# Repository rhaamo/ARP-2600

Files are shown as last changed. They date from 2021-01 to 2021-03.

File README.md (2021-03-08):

# ARP 2600
 
# Sources
- Patroche who did a lot of reverse on the schematics and PCBs http://www.crazy-patroche.com/article-clonage-du-arp-2600-120886590.html
- The 'full service manual'
- https://www.synthpatchers.com/wp-content/uploads/2013/05/ARP-2600-Slider-Locations-and-Values.pdf

# Status

| board | schematics | reviewed | pcb | tested |
| --- | --- | --- | --- | --- |
| 4014 ring modulator | done | | | |
| 4015 sample & hold  | done | | | |
| 4019 VCA | done | | | |
| 4020 ADSR | done | | | |
| 4022 Noise | done | | | |
| 4027 VCO | done | | | |
| 4072 VCF | done | | | |
| Board 1 | done | | | |
| Board 2 | done | | | |
| Board 2-1 | done | | | |
| Board 3 | done | | | |
| Board 4 | done | | | |
| Board 4-1 | done | | | |
| Board 5 | done | | | |
| Board 5-1 | done | | | |

# Notes
## All panel jacks
- check if they are properly labelled/wired

## Original schematics
- The jacks have S and T, S represent SHUNT, T for TIP, and the circle seems the SLEEVE
- an UP arrow is +15V, a DOWN arrow is -15V

## Patroche reverse
- Some typos presents, missing items in BOM, and some components are mislabelled in the PCB placement pictures

## Board 1
- On patroche, R27 (near S7) is R36

## Board 3
Adaptations have been made for 4072 VCF instead of 4012.

## Board 4
- Shouldn't `E57` and `E65` reverb input and output be internal RCA ?
- Some jacks / solder points don't have a number on schematics (given one arbitrary)
- two pairs of components have the same number too (changed one)

## Board 4-1
- one duplicate reference, some missing in patroche bom, one value differs from schematics

## Board 5-1
- In patroche PCB view, pin 1 and 4 are swapped from the schematics
- see notes in schematics for renamed parts

# Guidelines
- keep the same number as original schematics (R123, CR42, etc.)
- uses different prefix for Resistors (R), Trimmers (VR) and Faders (?), also to do that on existing made schematics.
- Jack sockets are `Exx`, hole for soldering a PANEL one or other wiring is `Txx`
- Use the PCBs from patroche to check for jacks on PCB vs panel and the associated 'pads' for the flying wires between boards
- Properly document thoses 'flying wires' like https://raw.githubusercontent.com/CreativeInquiry/ARP-2600/master/ARP-2600-Harness-Wiring.jpg but SVG/PDF with the board delimited and points/wire visibles. we don't have to wait until PCBs are done for that.
- PSU won't (yet) be recreated, you can use a newer, better one like https://www.muffwiggler.com/forum/viewtopic.php?t=130814&highlight= (PCB is available in 115 and 230V)
- Keyboard is not planned as CV/Gate is available on the panel, use your own midi-to-cv or keyboard with CV/Gate output
- Properly document in a separate file all changes between schematics/patroche (and our renaming of duplicates)

# Plans
1. Make identical boards as original/patroche
2. Maybe re-add the panel jacks to the bottom of PCBs
3. We will see

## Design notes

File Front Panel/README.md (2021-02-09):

- ARP 2600 Panel.orig.dxf

The original DXF converted from Patroche PDF

- ARP 2600 Panel.edited.dxf
- ARP 2600 Panel.edited.dwg

The DWG and DXF files edited to accomodate the changes in the BOM:

- power switch removed (it's integrated in the power socket)
- two leds (size changed, +1 led)
- jack headphones size update
- switches shape change
- gain pot size changed

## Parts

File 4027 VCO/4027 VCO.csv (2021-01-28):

Reference | Quantity | Value | Footprint | Datasheet | Notes
A1 | 1 | CA3086
C1 | 1 | 680pF |  | ~ | mica
C2 | 1 | 5pF |  | ~
C3 C6 | 2 | 10nF |  | ~
C4 C5 | 2 | 1uF 35V |  | ~ | chemical or tantal
J18 | 1 | L.F. CAP |  | ~
J19 | 1 | TRIM INPUT |  | ~
J2 | 1 | CONT. INPUT |  | ~
J5 | 1 | SAW. OUT |  | ~
J6 | 1 | POSITIVE SUPPLY |  | ~
J7 | 1 | GROUND |  | ~
J8 | 1 | NEGATIVE SUPPLY |  | ~
Q1 | 1 | 2N3906 | Package_TO_SOT_THT:TO-92_Inline | https://www.onsemi.com/pub/Collateral/2N3906-D.PDF
Q2 | 1 | 2N3904 | Package_TO_SOT_THT:TO-92_Inline | https://www.onsemi.com/pub/Collateral/2N3903-D.PDF
Q3 Q4 | 2 | 2N5459 |  | ~
Q5 | 1 | 2N4125 |  | ~
R1 | 1 | 475k 1% |  | ~
R10 | 1 | 30.1k 1% |  | ~
R11 | 1 | 3.9k |  | ~
R12 | 1 | 220R |  | ~
R13 | 1 | 1.65k 1% |  | ~
R3 R14 R21 | 3 | 1k 1% |  | ~
R15 | 1 | 8.87k 1% |  | ~
R16 | 1 | 1.37k 1% |  | ~
R18 | 1 | 47k |  | ~ | 41k ?
R19 | 1 | 68k |  | ~
R2 | 1 | 121k 1% |  | ~
R20 | 1 | 33.2k 1% |  | ~
R22 | 1 | 45.3k 1% |  | ~
R23 | 1 | 15k |  | ~
R24 | 1 | 3.3M |  | ~
R4 | 1 | 1.87k - tempco - 3500ppm 1w 3% |  | ~ | 1.87k - tempco - 3500ppm 1w 3%
R5 | 1 | 100k 1% |  | ~
R6 R7 | 2 | 61.9k 1% |  | ~
R8 R17 | 2 | 12k |  | ~
R9 | 1 | 1.5k |  | ~

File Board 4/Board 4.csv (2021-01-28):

Reference | Quantity | Value | Footprint | Datasheet
A20 | 1 | LM301 |  | http://www.ti.com/lit/ds/symlink/lm101a-n.pdf
BADSR-1 BADSR-2 BADSR-4 BVCA-5 BADSR-6 BVCA-6 BADSR-7 BVCA-7 BADSR-8 BVCA-8 SW8 BADSR-9 BVCA-9 BADSR-10 BVCA-10 BADSR-11 BVCA-11 BVCA-14 BVCA-18 BVCA-19 B42-1 B42-2 B42-3 B42-4 B42-5 B42-6 B42-7 B42-11 B42-12 B42-13 B42-14 B42-15 B42-16 B42-17 | 34 | ~ |  | ~
BADSR-5 B42-10 | 2 | +15V |  | ~
BADSR-3 B42-8 | 2 | -15V |  | ~
B42-9 | 1 | GND |  | ~
BVCA-1 | 1 | +control |  | ~
BVCA-2 | 1 | -control |  | ~
BVCA-3 | 1 | lin |  | ~
BVCA-4 | 1 | exp |  | ~
C62 C63 C64 C65 C69 | 5 | 1uF 35V |  | ~
C66 | 1 | 30pF |  | ~
C67 | 1 | 50pF |  | ~
C68 | 1 | 10uF 35V |  | ~
D21 D22 D23 D24 D25 | 5 | 1N4148 | Diode_THT:D_DO-35_SOD27_P7.62mm_Horizontal | https://assets.nexperia.com/documents/data-sheet/1N4148_1N4448.pdf
E45 E46 E47 E48 E50 E51 E52 E53 E55 E56 E57 E58 E59 E60 E62 E63 E64 E65 E66 E99 E100 | 21 | PJ301BM |  | https://www.thonk.co.uk/shop/3-5mm-jacks/
J100 | 1 | VCA OUT |  | ~
Q5 | 1 | 2N5460 |  | ~
Q6 | 1 | 2N5172 |  | ~
R170 | 1 | 2.2k |  | ~
R172 | 1 | 68k |  | ~
R173 | 1 | 3.9k |  | ~
R177 | 1 | 22k |  | ~
R174 R175 R179 R180 R182 | 5 | 1M LOG |  | ~
R183 | 1 | 9.1k 1% |  | ~
R184 | 1 | 10k 1% |  | ~
R192 | 1 | 54.9k 1% |  | ~
R176 R194 R195 R214 | 4 | 10k |  | ~
R197 | 1 | 150k |  | ~
R185 R186 R200 R201 | 4 | 100k LOG |  | ~
R189 R190 R191 R193 R196 R202 R203 | 7 | 100k |  | ~
R204 R206 | 2 | 1.2k |  | ~
R205 R207 | 2 | 820R |  | ~
R171 R178 R199 R208 | 4 | 1k |  | ~
R209 R211 | 2 | 33k |  | ~
R181 R187 R188 R198 R210 R212 R213 | 7 | 100k LIN |  | ~
SW1 | 1 | manual start |  | ~
T45 | 1 | FROM ??? ??? BOARD 5-1 |  | ~
T46 | 1 | KEYBOARD GATE |  | ~
T47 | 1 | TRIGGER |  | ~
T60 | 1 | output to left power amp |  | ~
T65 | 1 | output to right power amp |  | ~
T99 | 1 | TO VCA |  | ~

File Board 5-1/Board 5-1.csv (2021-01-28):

Reference | Quantity | Value | Footprint | Datasheet
A35 A36 A37 A38 A39 A40 A41 A42 | 8 | LM301 |  | http://www.ti.com/lit/ds/symlink/lm101a-n.pdf
C91 C98 C100 C102 | 4 | 30pF |  | ~
C104 C107 | 2 | 0.1uF |  | ~
C96 C105 C106 C109 C127 C128 | 6 | 10pF |  | ~
C111 C112 | 2 | 100pF |  | ~
C115 | 1 | 1.5uF 35V |  | ~
C116 C117 C118 C390 | 4 | 10nF |  | ~
C110 C113 C119 C120 | 4 | 1nF |  | ~
C88 C89 C123 C124 C125 C126 | 6 | 1uF 35V |  | ~
C97 C99 C101 C103 C108 C130 C341 | 7 | 20pF |  | ~
C90 | 1 | 20nF |  | ~
C92 | 1 | 2nF |  | ~
C93 | 1 | 50pF |  | ~
D45 D46 D47 D48 D49 D50 | 6 | 1N4148 | Diode_THT:D_DO-35_SOD27_P7.62mm_Horizontal | https://assets.nexperia.com/documents/data-sheet/1N4148_1N4448.pdf
J10 | 1 | LAG OUT |  | ~
J13 | 1 | LAG IN/TIME |  | ~
J18 | 1 | S/H EXT CLOCK IN |  | ~
J19 | 1 | S/H OUTPUT |  | ~
J20 J4015-1 | 2 | S/H INPUT |  | ~
J21 | 1 | CLOCK OUT |  | ~
J22 | 1 | 'B' |  | ~
J23 | 1 | 'C' |  | ~
J24 | 1 | 'A' |  | ~
J3 | 1 | NOISE |  | ~
J4 | 1 | NOISE COLOR |  | ~
J4015-4 | 1 | S/H CLOCK IN |  | ~
J11 J12 J4015-5 | 3 | OUT |  | ~
J4015-8 J4022-8 | 2 | -15V |  | ~
J5 | 1 | NOISE LEVEL |  | ~
J6 | 1 | NOISE OUT |  | ~
SPK1 SPK2 J7 J8 J14 J15 J17 J25 J26 J4022-5 | 10 | ~ |  | ~
JG0 JP5 JN6 JG8 JN9 JN15 J4015-7 J4022-2 J4022-7 | 9 | GND |  | ~
JP4 JP7 JP15 J4015-6 J4022-6 | 5 | +15V |  | ~
Q30 Q31 | 2 | D40D4 |  | ~
Q32 Q33 | 2 | D41D2 |  | ~
Q34 Q35 Q36 Q37 Q38 Q39 | 6 | 2N5172 |  | ~
Q40 Q41 | 2 | 2N4392 |  | ~
Q43 Q44 | 2 | 2N6076 |  | ~
Q45 | 1 | 2N4870 |  | ~
R326 | 1 | 270k |  | ~
R327 R328 | 2 | 5.6M |  | ~
R331 R337 | 2 | 100k 1% |  | ~
R340 | 1 | 1M |  | ~
R341 R351 R359 R369 R385 RV389 | 6 | 100k |  | ~
R344 R354 | 2 | 220k |  | ~
R345 R346 R355 R356 | 4 | 10R 1/2W |  | ~
R347 R375 R389 | 3 | 10k |  | ~
R325 R348 R386 R393 | 4 | 1k |  | ~
R349 R350 | 2 | 220R |  | ~
R357 R363 R370 R371 | 4 | 22M |  | ~
R358 R365 | 2 | 3.3M |  | ~
R343 R360 | 2 | 82k |  | ~
R361 R362 | 2 | 470k |  | ~
R366 R368 R399 | 3 | 150k |  | ~
R367 | 1 | 15k |  | ~
R372 R373 R374 R376 | 4 | 22k |  | ~
R380 | 1 | 68k |  | ~
R382 | 1 | 1.5k |  | ~
R383 | 1 | 100R |  | ~
R379 R387 | 2 | 4.7k |  | ~
R388 | 1 | 3.9k |  | ~
R324 R384 R390 R391 R392 | 5 | 47k |  | ~
R381 R394 | 2 | 1.8k |  | ~

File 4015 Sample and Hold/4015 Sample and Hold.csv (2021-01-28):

Reference | Quantity | Value | Footprint | Datasheet | notes
A1 A2 | 2 | LM301A |  | http://www.ti.com/lit/ds/symlink/lm101a-n.pdf
C1 C2 | 2 | 0.01uF |  | ~ | ceramic
C3 C5 C6 | 3 | 20pF |  | ~ | ceramic
C4 C7 | 2 | 30pF |  | ~ | ceramic
C8 | 1 | 22nF polycarbonate |  | ~ | polycarbonate
D1 D2 D3 D4 | 4 | 1N4148 | Diode_THT:D_DO-35_SOD27_P7.62mm_Horizontal | https://assets.nexperia.com/documents/data-sheet/1N4148_1N4448.pdf
J1 | 1 | INPUT |  | ~
J4 | 1 | SAMPLE IN |  | ~
J5 | 1 | OUTPUT |  | ~
J6 | 1 | POSITIVE SUPPLY |  | ~
J7 | 1 | GROUND |  | ~
J8 | 1 | NEGATIVE SUPPLY |  | ~
Q1 Q3 Q6 | 3 | 2N5172 |  | ~
Q2 Q5 | 2 | 2N3906 | Package_TO_SOT_THT:TO-92_Inline | https://www.onsemi.com/pub/Collateral/2N3906-D.PDF
Q4 Q7-1 Q7-2 | 3 | BF245A or 2SK30 | Package_TO_SOT_THT:TO-92_Inline | https://www.onsemi.com/pub/Collateral/BF245A-D.PDF
R1 R18 | 2 | 61.9k 1% |  | ~
R10 | 1 | 330R |  | ~
R11 | 1 | 33k |  | ~
R13 | 1 | 15k |  | ~
R15 | 1 | 4.7k |  | ~
R16 | 1 | 1k |  | ~
R2 R17 | 2 | 30.1k 1% |  | ~
R3 | 1 | 22k |  | ~
R6 R7 | 2 | 56R |  | ~
R8 R21 R22 | 3 | 100k |  | ~
R9 R12 R14 | 3 | 10k |  | ~

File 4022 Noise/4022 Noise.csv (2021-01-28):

Reference | Quantity | Value | Footprint | Datasheet | Notes
C1 | 1 | 1uF 35V |  | ~ | electrolytic or tantal
C3 | 1 | 3.3nF |  | ~ | plastic
C2 C4 C5 | 3 | 10nF |  | ~ | plastic
J2 J7 | 2 | GROUND |  | ~
J5 | 1 | OUTPUT |  | ~
J6 | 1 | POSITIVE SUPPLY |  | ~
J8 | 1 | NEGATIVE SUPPLY |  | ~
Q1 | 1 | 2N5172 |  | ~
R1 R2 | 2 | 100k |  | ~
R3 R4 | 2 | 4.7M |  | ~
R5 | 1 | 1.5k |  | ~
R6 | 1 | 3.9k |  | ~
Z1 | 1 | LM301A |  | http://www.ti.com/lit/ds/symlink/lm101a-n.pdf

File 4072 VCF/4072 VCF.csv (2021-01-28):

Reference | Quantity | Value | Footprint | Datasheet | Notes
C1 C2 C3 C4 | 4 | 4700pF |  | ~ | plastic caps
C5 | 1 | 0.01uF |  | ~ | ceramic
C7 C8 C9 C10 C11 | 5 | 1uF 35V |  | ~ | chemical or tantal; orig 10uF
CR1 | 1 | 1N4148 | Diode_THT:D_DO-35_SOD27_P7.62mm_Horizontal | https://assets.nexperia.com/documents/data-sheet/1N4148_1N4448.pdf
J1 | 1 | NON-INVERTING INPUT |  | ~
J10 | 1 | GAIN TRIM |  | ~
J14 J18 | 2 | CVR TRIM |  | ~
J2 | 1 | INVERTING INPUT |  | ~
J3 J9 | 2 | Fc CONTROL INPUT |  | ~
J5 | 1 | OUTPUT |  | ~
J6 | 1 | POSITIVE SUPPLY |  | ~
J7 | 1 | GROUND |  | ~
J8 | 1 | NEGATIVE SUPPLY |  | ~
Q13 | 1 | 2N3904 | Package_TO_SOT_THT:TO-92_Inline | https://www.onsemi.com/pub/Collateral/2N3903-D.PDF
Q14 Q15 Q16 Q17 | 4 | 2N3906 | Package_TO_SOT_THT:TO-92_Inline | https://www.onsemi.com/pub/Collateral/2N3906-D.PDF
Q1 Q2 Q3 Q4 Q5 Q6 Q7 Q8 Q9 Q10 | 10 | 2N5087 |  | ~
R1 R6 R11 R16 R21 R22 R23 | 7 | 12.1k 1% |  | ~
R2 R7 R12 R17 R36 | 5 | 2.2k |  | ~ | orig 4.7k lesser cut-off range
R24 | 1 | 56k |  | ~
RV1 R25 R26 | 3 | 100k |  | ~
R27 | 1 | 270k |  | ~
R28 | 1 | 1.87k tempco +3500ppm/k 1W 3% |  | ~ | https://www.thonk.co.uk/shop/tempco-resistor-krl-bantry-3500ppm-x2/
R29 | 1 | 196k 1% |  | ~
R3 R4 R8 R9 R13 R14 R18 R19 R35 | 9 | 220R |  | ~
R30 | 1 | 39k |  | ~
R31 | 1 | 4.7k |  | ~
R32 R33 R37 | 3 | 10k |  | ~
R34 | 1 | 100R |  | ~
R38 | 1 | 220k |  | ~
R39 | 1 | 1.3k |  | ~
R40 R41 R44 | 3 | 13k 1% |  | ~
R42 R43 | 2 | 100k 1% |  | ~
R45 | 1 | 1k |  | ~
R5 R10 R15 R20 | 4 | 22M 1% |  | ~
Z1 | 1 | LM3900
Z2 | 1 | LM1458 |  | http://www.ti.com/lit/ds/symlink/lm358.pdf

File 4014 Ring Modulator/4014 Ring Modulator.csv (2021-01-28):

Reference | Quantity | Value | Footprint | Datasheet | orig value
A1 A2 | 2 | LM301 |  | http://www.ti.com/lit/ds/symlink/lm101a-n.pdf | LM301A
C1 | 1 | 12pF |  | ~
C2 | 1 | 220pF |  | ~
C5 | 1 | 10pF |  | ~
C3 C4 C6 | 3 | 50pF |  | ~
C7 C8 | 2 | 0.01uF |  | ~
C9 | 1 | 100pF |  | ~
CR1 CR2 CR3 CR4 CR5 CR6 | 6 | 1N4148 | Diode_THT:D_DO-35_SOD27_P7.62mm_Horizontal | http://www.vishay.com/docs/85622/1n914.pdf | 1N914
J10 | 1 | NEG. NULL |  | ~
J18 | 1 | POS. NULL |  | ~
J2 | 1 | Y INPUT |  | ~
J4 | 1 | X INPUT |  | ~
J5 | 1 | OUTPUT |  | ~
J6 | 1 | POSITIVE SUPPLY |  | ~
J7 | 1 | GROUND |  | ~
J8 | 1 | NEGATIVE SUPPLY |  | ~
J9 | 1 | GAIN TRIM |  | ~
Q1 Q2 Q3 Q9 Q10 Q12 | 6 | 2N3906 |  | ~ | TZ-581
Q4 Q5 Q6 Q7 Q8 Q11 | 6 | 2N3904 |  | ~ | TZ-81
R1 R2 | 2 | 4.7k |  | ~
R10 | 1 | 1M |  | ~
R8 R11 R12 | 3 | 18k |  | ~
R14 | 1 | 470R |  | ~
R15 | 1 | 27k |  | ~
R16 | 1 | 180k |  | ~
R18 | 1 | 82k |  | ~
R3 R13 | 2 | 220R |  | ~
R4 R7 | 2 | 680R |  | ~
R5 R6 | 2 | 1.5M |  | ~

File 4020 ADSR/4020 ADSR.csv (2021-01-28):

Reference | Quantity | Value | Footprint | Datasheet | Notes
A1 | 1 | LM301A |  | http://www.ti.com/lit/ds/symlink/lm101a-n.pdf
C3 | 1 | 330pF |  | ~ | ceramic
C4 | 1 | 10nF |  | ~ | ceramic
C5 | 1 | 1nF |  | ~ | ceramic
C1 C2 C6 C7 | 4 | 1uF 35V |  | ~ | tantal
CR1 CR2 CR3 CR4 CR5 CR6 CR7 CR8 | 8 | 1N4148 | Diode_THT:D_DO-35_SOD27_P7.62mm_Horizontal | https://assets.nexperia.com/documents/data-sheet/1N4148_1N4448.pdf
J1 | 1 | TRIGGER INPUT |  | ~
J10 | 1 | DECAY/SUSTAIN |  | ~
J11 | 1 | RELEASE |  | ~
J2 | 1 | GATE INPUT |  | ~
J3 | 1 | NEGATIVE SUPPLY |  | ~
J4 J7 | 2 | GROUND |  | ~
J5 | 1 | POSITIVE SUPPLY |  | ~
J6 | 1 | ADSR OUTPUT |  | ~
J8 J9 | 2 | ATTACK |  | ~
Q2 Q7 Q8 | 3 | 2N5172 |  | ~
Q3 | 1 | 2SK30 |  | ~ | Orig: LS4302
Q4 | 1 | 2N5460 |  | ~
Q1 Q5 | 2 | 2N3906 | Package_TO_SOT_THT:TO-92_Inline | https://www.onsemi.com/pub/Collateral/2N3906-D.PDF | Orig: TZ5(?)81
Q6 | 1 | 2N5367 or 2N3906 |  | ~
R1 | 1 | 270k |  | ~
R10 | 1 | 120R |  | ~
R11 | 1 | 40.2k 1% |  | ~
R12 | 1 | 1k |  | ~
R13 | 1 | 68.1k 1% |  | ~
R14 | 1 | 100k |  | ~
R15 | 1 | 4.7k |  | ~
R16 | 1 | 39k |  | ~
R18 | 1 | 470k |  | ~
R17 R19 | 2 | 68k |  | ~
R2 | 1 | 22k |  | ~
R20 | 1 | 120k |  | ~
R23 | 1 | 12k |  | ~
R24 | 1 | 1.5k |  | ~
R3 | 1 | 1.2M |  | ~
R4 R22 | 2 | 180k |  | ~
R5 | 1 | 15k |  | ~
R6 R9 | 2 | 1M |  | ~
R7 | 1 | 10k |  | ~
R8 | 1 | 33k |  | ~

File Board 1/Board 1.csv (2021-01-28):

Reference | Quantity | Value | Footprint | Datasheet | Notes
A1 A2 A3 A4 | 4 | LM301 |  | http://www.ti.com/lit/ds/symlink/lm101a-n.pdf | If TL071, remove caps between pin 1 and 8
C1 C8 C24 | 3 | 100nF |  | ~ | ceramic
C10 | 1 | 2nF |  | ~ | ceramic
C12 | 1 | 1nF |  | ~ | ceramic
C15 | 1 | 50pF |  | ~ | ceramic
C16 | 1 | 5pF |  | ~ | ceramic
C13 C14 C18 C19 C20 C21 | 6 | 10uF 35V |  | ~ | electrolytic
C7 C22 C23 | 3 | 1uF 35V |  | ~ | electrolytic
C3 C6 | 2 | 30pF |  | ~ | ceramic
C9 | 1 | 10nF |  | ~ | ceramic
D1 D2 | 2 | 1N4148 | Diode_THT:D_DO-35_SOD27_P7.62mm_Horizontal | https://assets.nexperia.com/documents/data-sheet/1N4148_1N4448.pdf
E1 E2 E3 E4 E5 E6 E7 | 7 | PJ301BM |  | https://www.thonk.co.uk/shop/3-5mm-jacks/
J10 | 1 | NEG. NULL |  | ~
J18 | 1 | POS. NULL |  | ~
J2 | 1 | Y INPUT |  | ~
J3 | 1 | X INPUT |  | ~
J5 | 1 | OUTPUT |  | ~
J6 | 1 | +15V |  | ~
J8 | 1 | -15V |  | ~
J9 | 1 | GAIN TRIM |  | ~
JGND1 J7 | 2 | GND |  | ~
JN15 | 1 | NEGATIVE SUPPLY |  | ~
JP15 | 1 | POSITIVE SUPPLY |  | ~
R1 | 1 | 82k |  | ~
R12 | 1 | 2.7k |  | ~
R13 | 1 | 27k |  | ~
R14 | 1 | 270k |  | ~
R15 | 1 | 1M |  | ~
R16 | 1 | 1.5M |  | ~
R17 | 1 | 10M |  | ~
R2 R29 R31 | 3 | 100k LIN |  | ~
R23 | 1 | 100k LOG |  | ~
R20 R24 | 2 | 100k |  | ~
R18 R25 R27 R36 | 4 | 1k |  | ~
R19 R26 | 2 | 10k |  | ~
R28 | 1 | 100R |  | ~
R3 R6 R7 R8 R9 | 5 | 100k 1% |  | ~
R30 | 1 | 47k |  | ~
R32 | 1 | 18k |  | ~
R33 R34 | 2 | 50k |  | ~
R35 | 1 | 250k |  | ~
R37 | 1 | 39k |  | ~
R38 | 1 | 120k |  | ~
S1 | 1 | GAIN
S2 | 1 | AUD / DC
T1 T2 T4 T5 T6 T7 | 6 | TIP |  | ~

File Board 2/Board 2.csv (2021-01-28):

Reference | Quantity | Value | Footprint | Datasheet | Notes
C34 C35 C36 C37 C38 C39 | 6 | 1uF 35v |  | ~ | electrolytic
C40 C41 C42 | 3 | 0.015uF 10% plastic |  | ~ | plastic
C43 C44 | 2 | 3.3pF 10% |  | ~ | ceramic
D7 D8 D9 | 3 | 1N4148 | Diode_THT:D_DO-35_SOD27_P7.62mm_Horizontal | https://assets.nexperia.com/documents/data-sheet/1N4148_1N4448.pdf
E13 E14 E15 E16 E17 E18 E19 E20 E21 E22 E23 E24 E25 E26 E27 E28 E29 E30 E31 E32 E33 | 21 | PJ301BM |  | https://www.thonk.co.uk/shop/3-5mm-jacks/
JPWR11 JPWR21 JPWR31 | 3 | POSITIVE SUPPLY |  | ~
JPWR12 TVCO1-7 JPWR22 TVCO2-7 JPWR32 TVCO3-7 TVBD21-5 | 7 | GND |  | ~
JPWR13 JPWR23 JPWR33 | 3 | NEGATIVE SUPPLY |  | ~
R53 R58 R71 R75 R94 R100 R105 R107 R109 | 9 | 220k |  | ~
R111 | 1 | 15k |  | ~
R18 R41 R42 R52 R64 R66 R68 R70 R82 R83 R85 R87 R92 | 13 | 100k LIN |  | ~
R43 R65 R84 | 3 | 150k 1% |  | ~
R44 R67 R86 | 3 | 3.3M |  | ~
R45 | 1 | 6.8k |  | ~
R46 R47 | 2 | 33k |  | ~
R48 | 1 | 8.2k |  | ~
R49 R50 R104 R106 R108 R110 | 6 | 1k |  | ~
R51 R89 | 2 | 3.9k |  | ~
R56 R72 R95 | 3 | 84.5k 1% |  | ~
R57 R74 R98 | 3 | 100k 1% |  | ~
R59 R76 R101 | 3 | 470k |  | ~
R60 R78 R97 | 3 | 25k LIN |  | ~
R61 R62 R63 R79 R80 R81 R99 R102 R103 | 9 | 100k LOG |  | ~
R77 | 1 | 120k |  | ~
R88 | 1 | 1M |  | ~
R90 | 1 | 30.1k 1% |  | ~
R91 | 1 | 45.3k 1% |  | ~
CV-1 CV-2 CV-3 S15 T15 T16 T17 T18 T19 S22 T22 T23 T24 T25 T26 T27 S29 T29 T30 T31 T32 | 21 | ~ |  | ~
S4 S5 S6 | 3 | AUD/LF
T13 | 1 | OVPP |  | ~
T14 | 1 | RING MOD |  | ~
T20 | 1 | VCF |  | ~
T33 T33-1 | 2 | VCO 3 |  | ~
TVBD21-1 | 1 | PULSE WIDTH |  | ~
TVBD21-2 | 1 | SAWTOOTH IN |  | ~
TVBD21-3 | 1 | PULSE OUT |  | ~
TVBD21-7 | 1 | PWM IN |  | ~
TVBD21-8 | 1 | SIN OUT |  | ~
TVBD21-9 | 1 | TRIANGLE OUT |  | ~
TVCO1-18 TVCO2-18 TVCO3-18 | 3 | L.F. CAP |  | ~
TVCO1-19 TVCO2-19 TVCO3-19 | 3 | TRIM INPUT |  | ~
TVCO1-2 TVCO2-2 TVCO3-2 | 3 | CONT. INPUT |  | ~
TVCO1-5 TVCO2-5 TVCO3-5 | 3 | SAW. OUT |  | ~
TVCO1-6 TVCO2-6 TVCO3-6 TVBD21-4 | 4 | +15V |  | ~
TVCO1-8 TVCO2-8 TVCO3-8 TVBD21-6 | 4 | -15V |  | ~
Z8 Z9 | 2 | LM301 |  | http://www.ti.com/lit/ds/symlink/lm101a-n.pdf

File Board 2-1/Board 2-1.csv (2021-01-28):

Reference | Quantity | Value | Footprint | Datasheet | Notes
A14 A15 A16 A17 | 4 | LM301 |  | http://www.ti.com/lit/ds/symlink/lm101a-n.pdf
C51 C52 | 2 | 1uF |  | ~ | electrolytic
C50 C54 C55 | 3 | 30pF |  | ~ | ceramic
C53 C56 | 2 | 100pF |  | ~ | ceramic
D14 | 1 | 1N4148 | Diode_THT:D_DO-35_SOD27_P7.62mm_Horizontal | https://assets.nexperia.com/documents/data-sheet/1N4148_1N4448.pdf
J1 | 1 | FROM PULSE WIDTH SLIDER |  | ~
J2 | 1 | SAWTOOTH FROM VCO-2 |  | ~
J3 | 1 | PULSE WAVE OUTPUT |  | ~
J4 | 1 | POSITIVE SUPPLY |  | ~
J5 | 1 | GND |  | ~
J6 | 1 | NEGATIVE SUPPLY |  | ~
J7 | 1 | PULSE WIDTH MOD IN |  | ~
J8 | 1 | SINE WAVE OUTPUT |  | ~
J9 | 1 | TRIANGLE WAVE OUT |  | ~
Q1 | 1 | 2N3906 | Package_TO_SOT_THT:TO-92_Inline | https://www.onsemi.com/pub/Collateral/2N3906-D.PDF
Q2 | 1 | 2N5172 |  | ~
Q3-1 Q3-2 | 2 | 2SK30 |  | ~
R109 R112 | 2 | 33k |  | ~
R110 | 1 | 193k 1% |  | ~
R111 | 1 | 121k 1% |  | ~
R113 R132 R133 | 3 | 2.2k |  | ~
R114 | 1 | 39k |  | ~
R115 R125 | 2 | 100k |  | ~
R116 R117 R131 | 3 | 1k |  | ~
R118 | 1 | 30k |  | ~
R119 R121 | 2 | 15k 1% |  | ~
R120 | 1 | 10k 1% |  | ~
R122 R123 R126 | 3 | 30.1k 1% |  | ~
R124 | 1 | 68k |  | ~
R134 | 1 | 180k |  | ~
R135 | 1 | 22k |  | ~
RV121 R128 | 2 | 10k |  | ~

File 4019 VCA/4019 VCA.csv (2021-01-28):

Reference | Quantity | Value | Footprint | Datasheet | Notes
A1 | 1 | LM301A |  | http://www.ti.com/lit/ds/symlink/lm101a-n.pdf
C1 C2 | 2 | 10nF |  | ~ | ceramic
C3 | 1 | 30pF |  | ~ | ceramic
C4 | 1 | 10pF |  | ~ | ceramic
C5 C6 | 2 | 100pF |  | ~ | ceramic
C7 | 1 | 220pF |  | ~ | ceramic
CR1 CR2 CR3 CR4 CR5 CR6 CR7 CR8 CR9 CR10 | 10 | 1N4148 | Diode_THT:D_DO-35_SOD27_P7.62mm_Horizontal | https://assets.nexperia.com/documents/data-sheet/1N4148_1N4448.pdf
J1 | 1 | AUDIO + |  | ~
J10 J14 | 2 | LINEAR GAIN |  | ~
J11 | 1 | HIGH FREQ. REJECT |  | ~
J18 | 1 | EXPONENTIAL GAIN |  | ~
J19 | 1 | REJECTION CONTROL |  | ~
J2 | 1 | AUDIO - |  | ~
J3 | 1 | LINEAR INPUT |  | ~
J4 | 1 | INPUT |  | ~
J5 | 1 | OUTPUT |  | ~
J6 | 1 | POSITIVE SUPPLY |  | ~
J7 | 1 | GROUND |  | ~
J8 | 1 | NEGATIVE SUPPLY |  | ~
J9 | 1 | NC |  | ~
Q1 Q6 Q7 Q9 Q10 | 5 | 2N3906 | Package_TO_SOT_THT:TO-92_Inline | https://www.onsemi.com/pub/Collateral/2N3906-D.PDF
Q11 | 1 | 2N5249 or 2N3904 | Package_TO_SOT_THT:TO-92_Inline | https://www.onsemi.com/pub/Collateral/2N3903-D.PDF
Q2 Q12 Q13 | 3 | 2N3904 | Package_TO_SOT_THT:TO-92_Inline | https://www.onsemi.com/pub/Collateral/2N3903-D.PDF
Q3 Q4 Q8 | 3 | 2N6076 or 2N3906 | Package_TO_SOT_THT:TO-92_Inline | https://www.onsemi.com/pub/Collateral/2N3906-D.PDF
Q5 | 1 | 2N5172 |  | ~
R11 | 1 | 100k |  | ~
R12 | 1 | 180k |  | ~
R13 | 1 | 18k |  | ~
R15 R19 R23 | 3 | 4.7k |  | ~
R18 | 1 | 680k |  | ~
R2 | 1 | 470k |  | ~
R17 R21 | 2 | 220R |  | ~
R24 R26 | 2 | 56k |  | ~
R3 | 1 | 182k M.F. 1% |  | ~
R4 | 1 | 3.3k |  | ~
R5 R16 R20 | 3 | 1k |  | ~
R6 | 1 | 1.5M |  | ~
R7 | 1 | 470R |  | ~
R8 | 1 | 33k |  | ~
R9 | 1 | 47k |  | ~

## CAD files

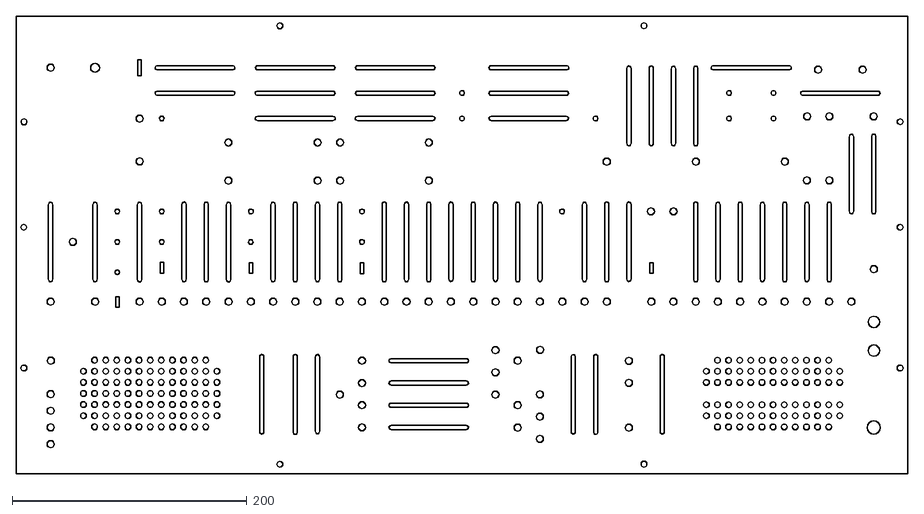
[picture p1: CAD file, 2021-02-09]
Front Panel/ARP 2600 Panel.edited.dxf
760.0 x 390.0

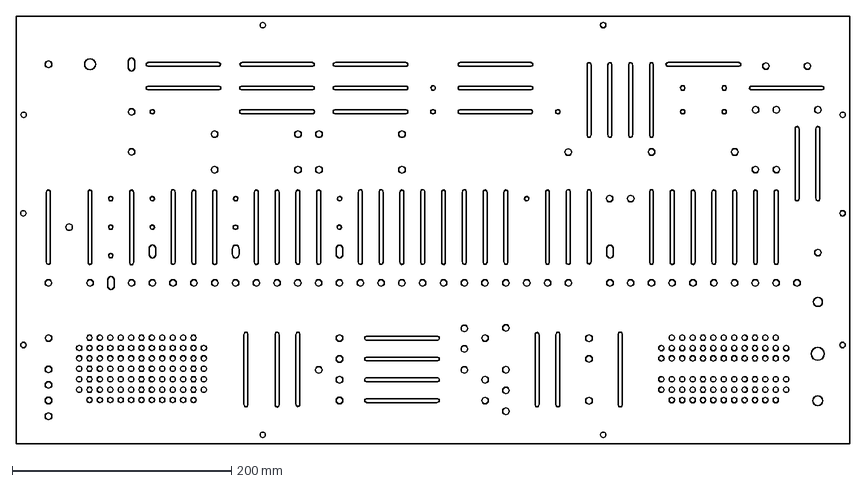
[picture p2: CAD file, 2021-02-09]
Front Panel/ARP 2600 Panel.orig.dxf
760.0 x 390.0 mm

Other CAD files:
Front Panel/ARP 2600 Panel.edited.dwg

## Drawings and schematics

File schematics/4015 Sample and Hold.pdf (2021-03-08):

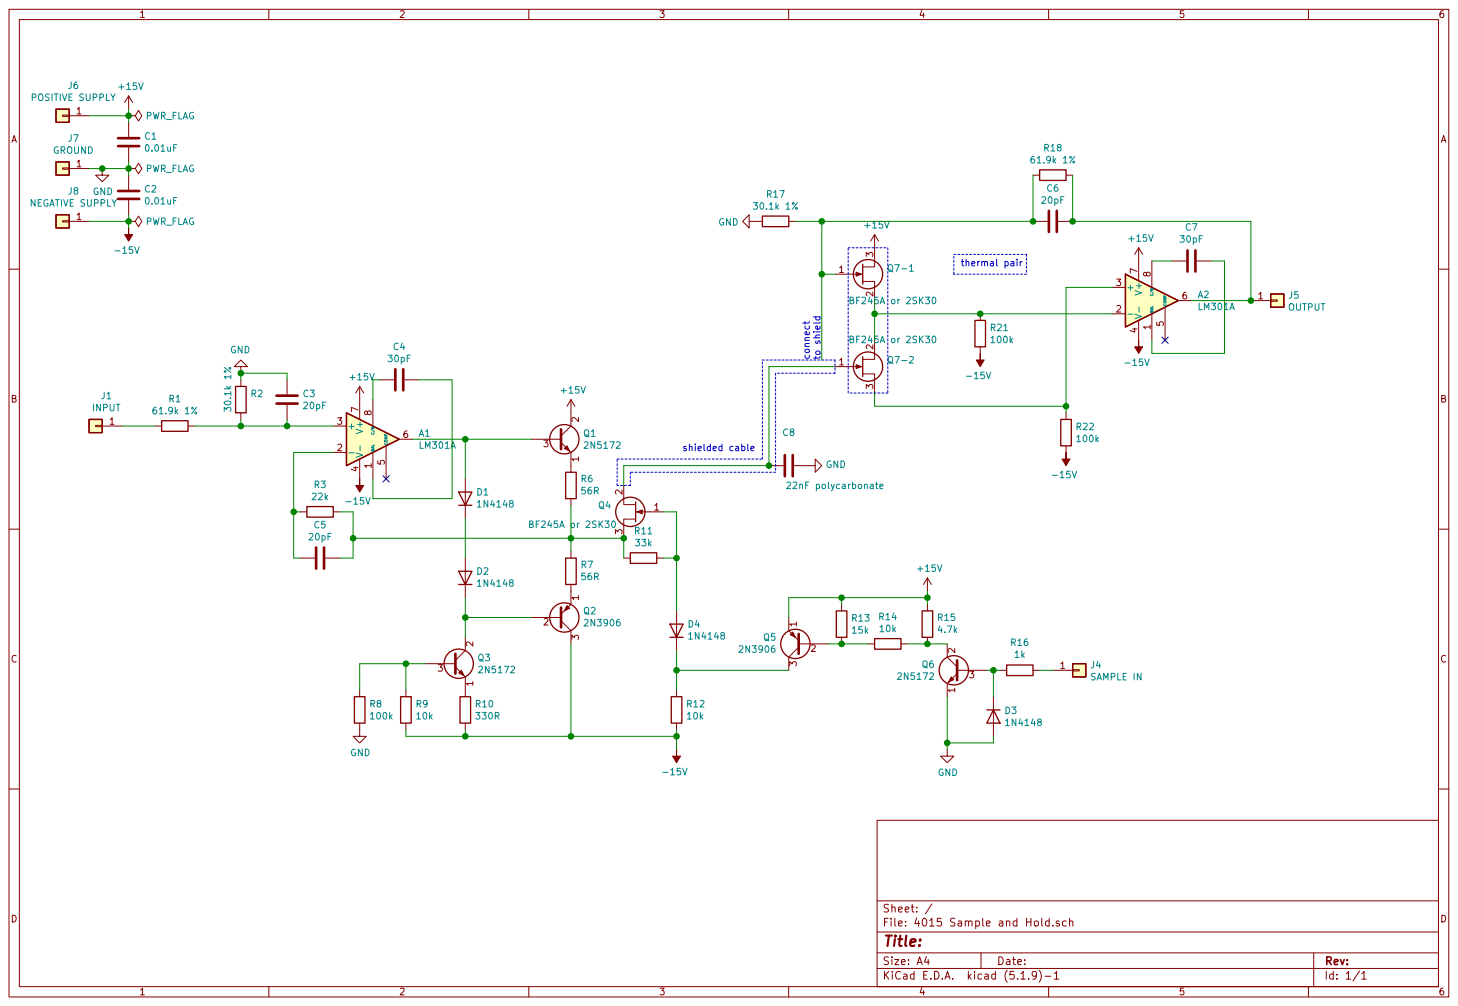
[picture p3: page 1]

File: 4015 Sample and Hold.sch Sheet: /
Id: 1/1 Title:

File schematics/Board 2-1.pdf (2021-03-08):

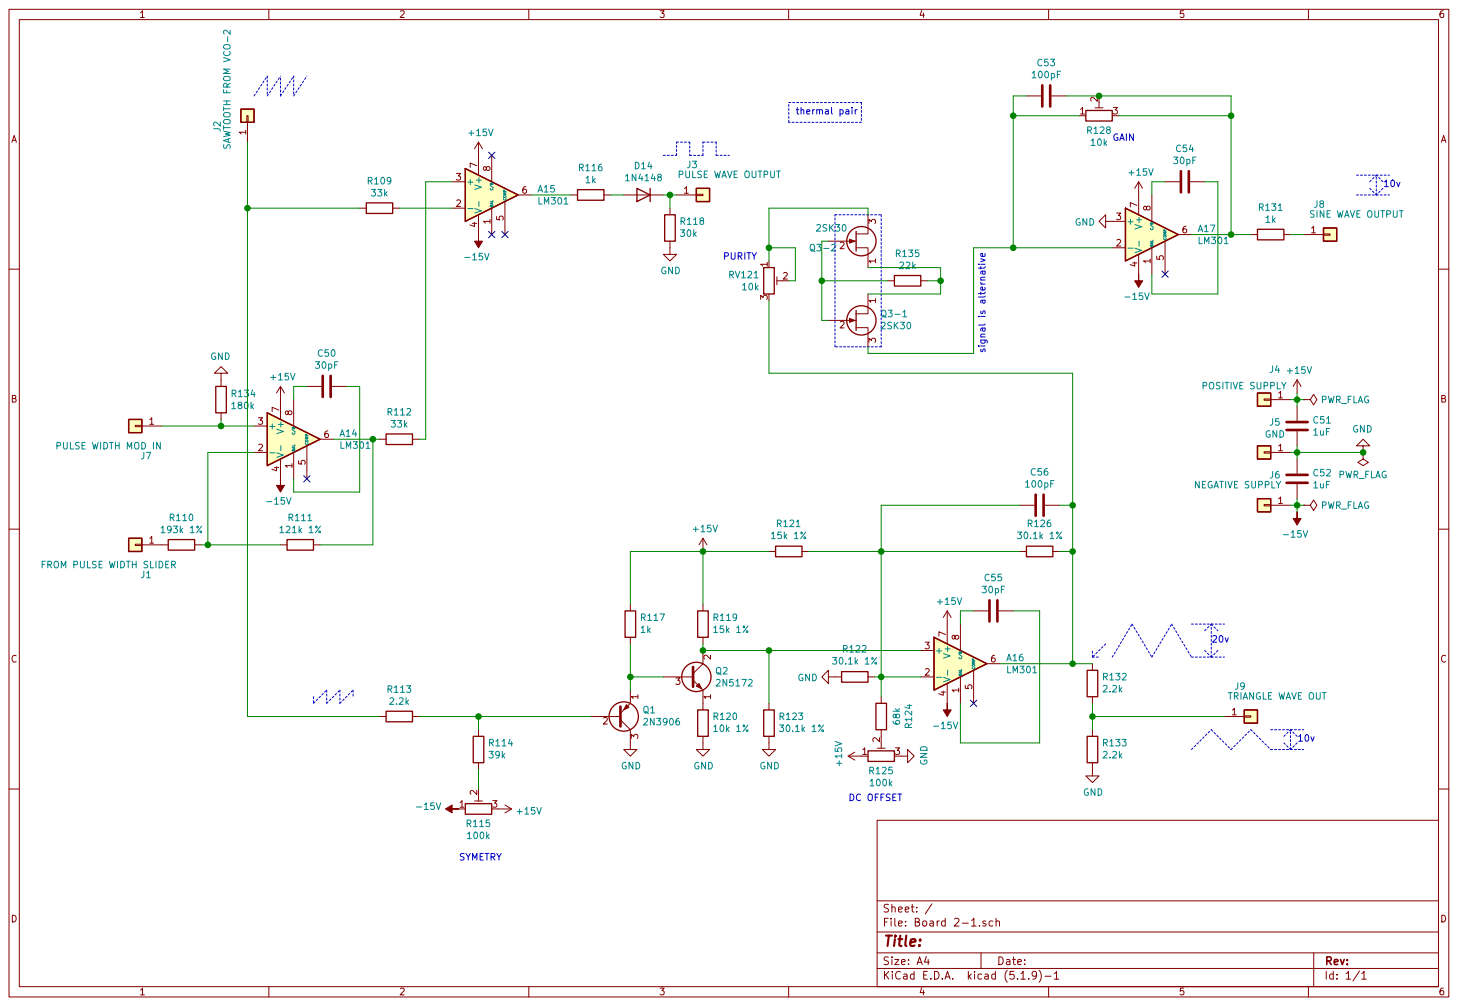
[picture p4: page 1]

J1 FROM PULSE WIDTH SLIDER

Id: 1/1 Title: File: Board 2-1.sch Sheet: / R120

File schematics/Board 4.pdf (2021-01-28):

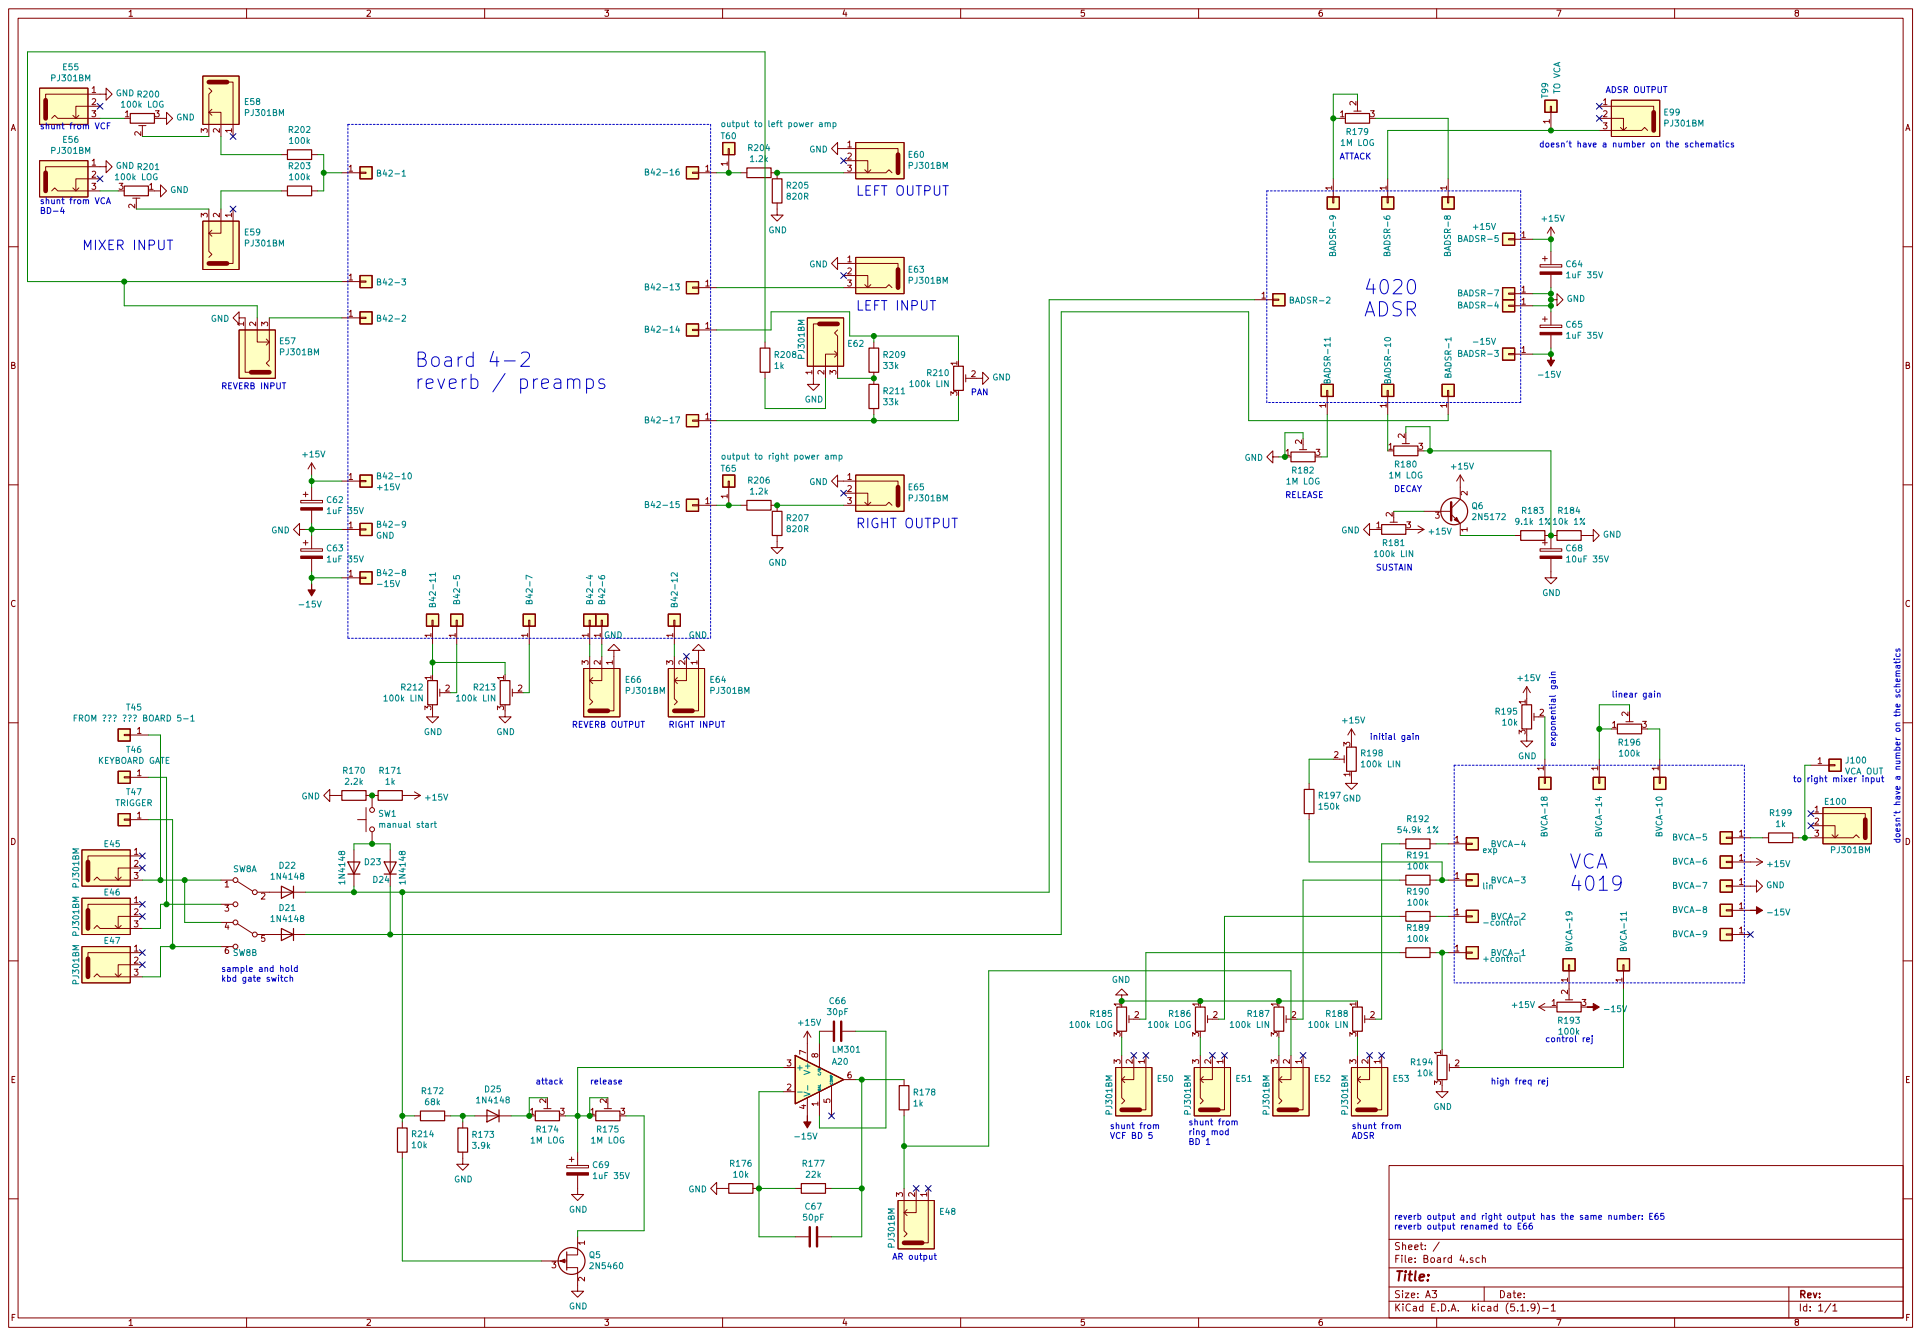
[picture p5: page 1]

output to left power amp GND

doesn't have a number on the schematics RIGHT INPUT

output to right power amp

to right mixer input

reverb output and right output has the same number: E65

Id: 1/1 Title: File: Board 4.sch Sheet: /

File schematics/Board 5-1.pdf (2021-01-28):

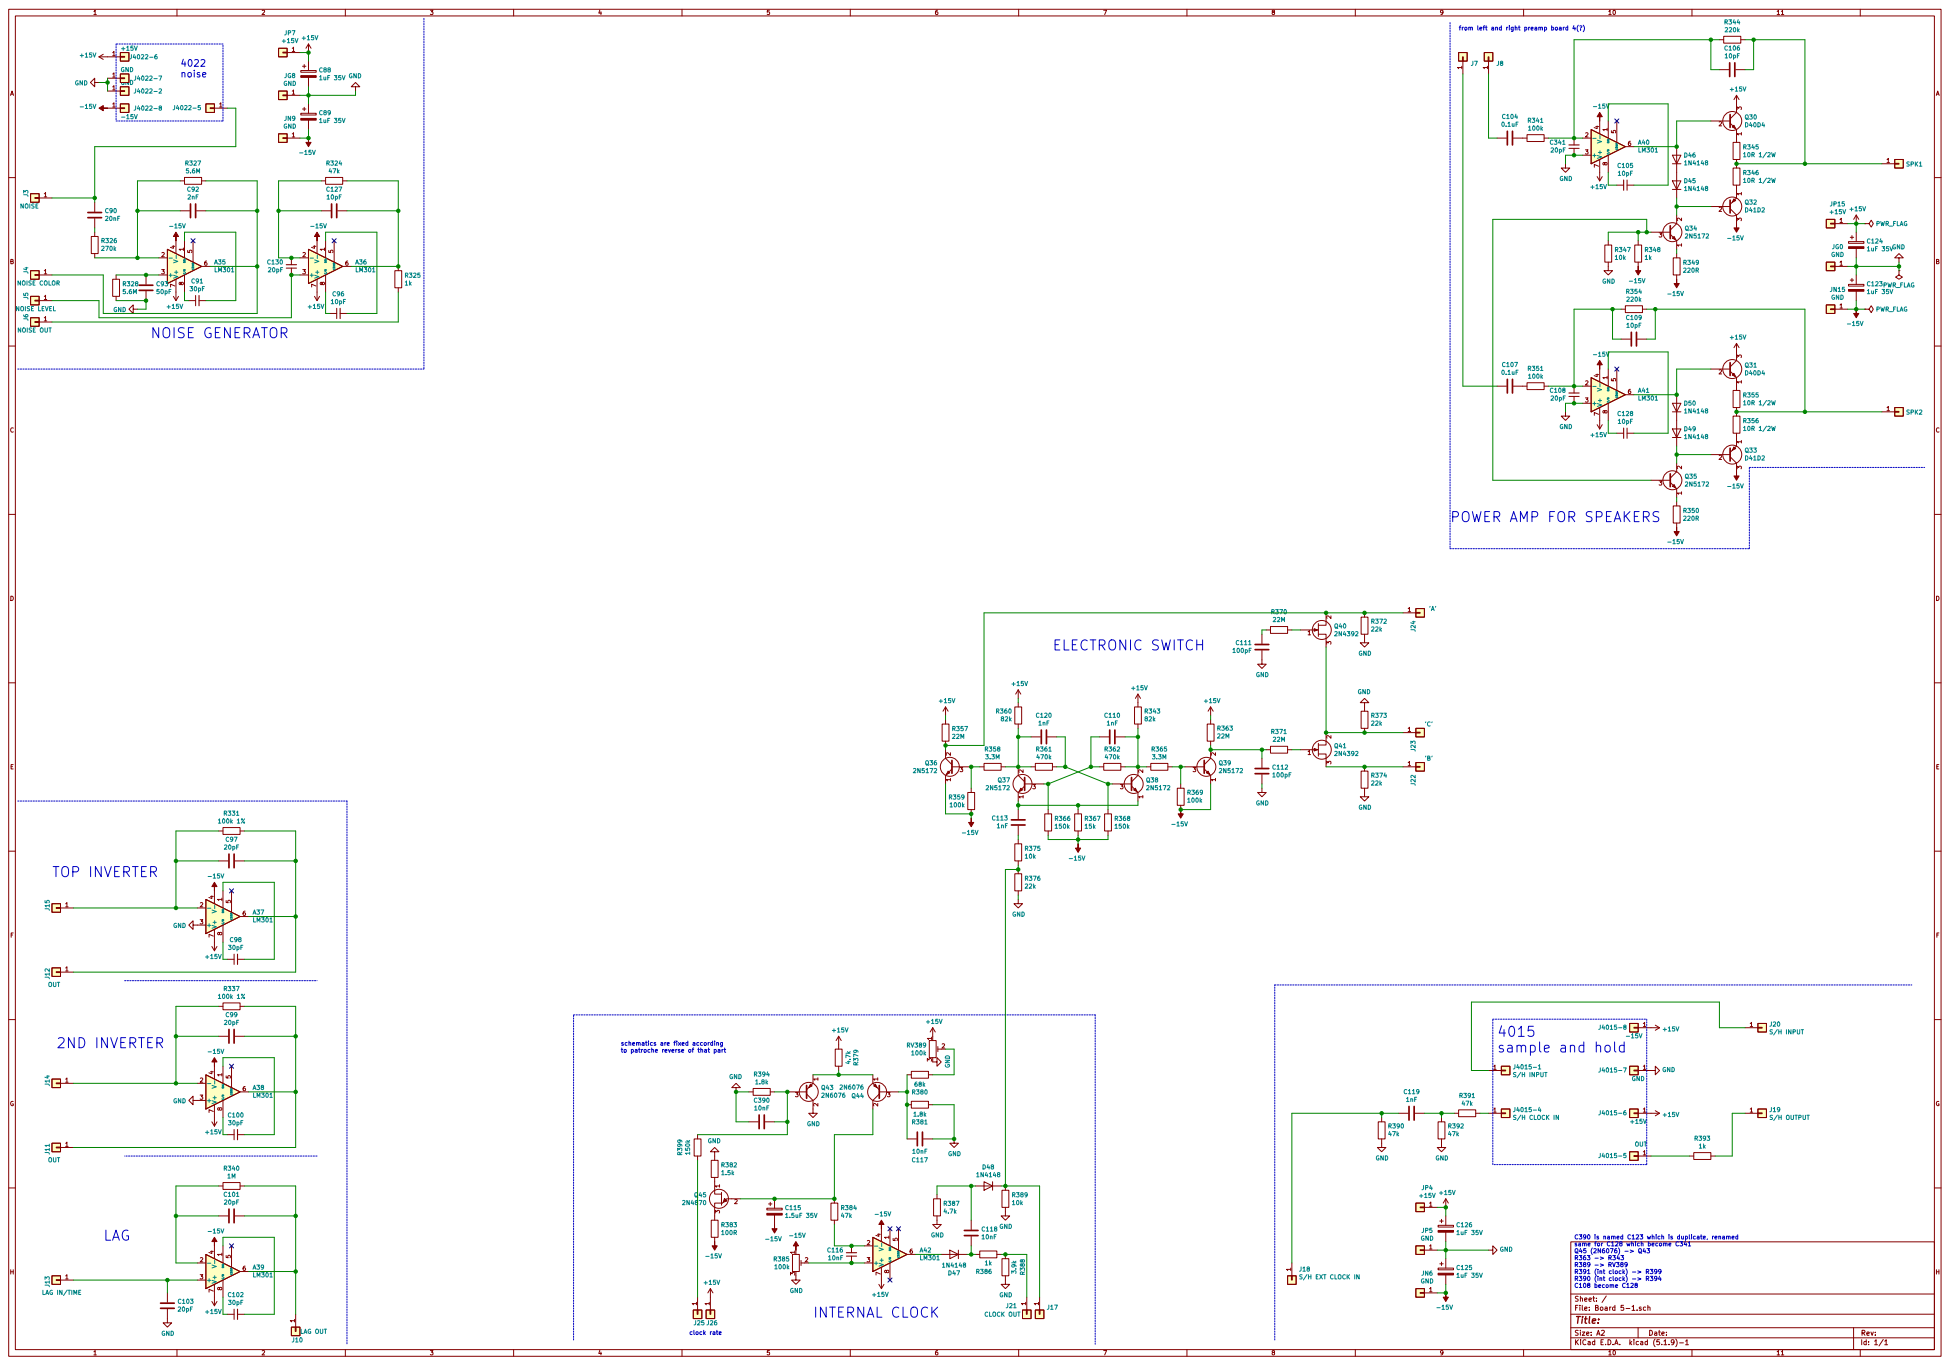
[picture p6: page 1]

from left and right preamp board 4(?)

POWER AMP FOR SPEAKERS

to patroche reverse of that part

Id: 1/1 Title: File: Board 5-1.sch Sheet: / C101

C390 is named C123 which is duplicate, renamed
same for C128 which become C341 Q45 (2N6076) -> Q43 R363 -> R343 R389 -> RV389 R391 (int clock) -> R399

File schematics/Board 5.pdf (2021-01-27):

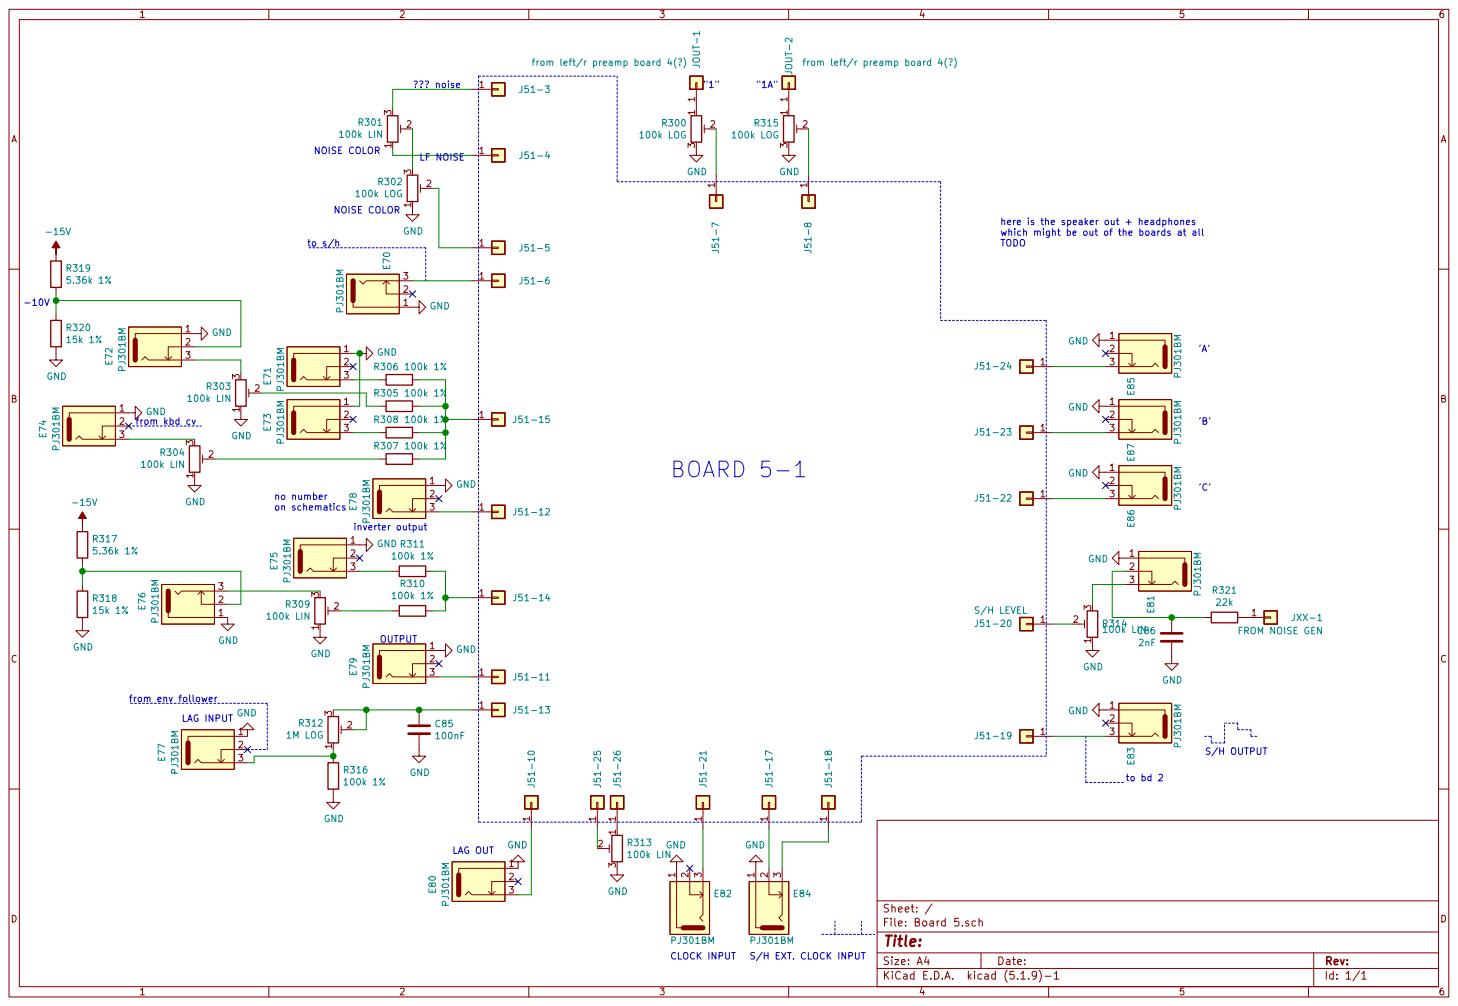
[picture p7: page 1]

1 JOUT-2 from left/r preamp board 4(?) 1

which might be out of the boards at all TODO

JXX-1 FROM NOISE GEN

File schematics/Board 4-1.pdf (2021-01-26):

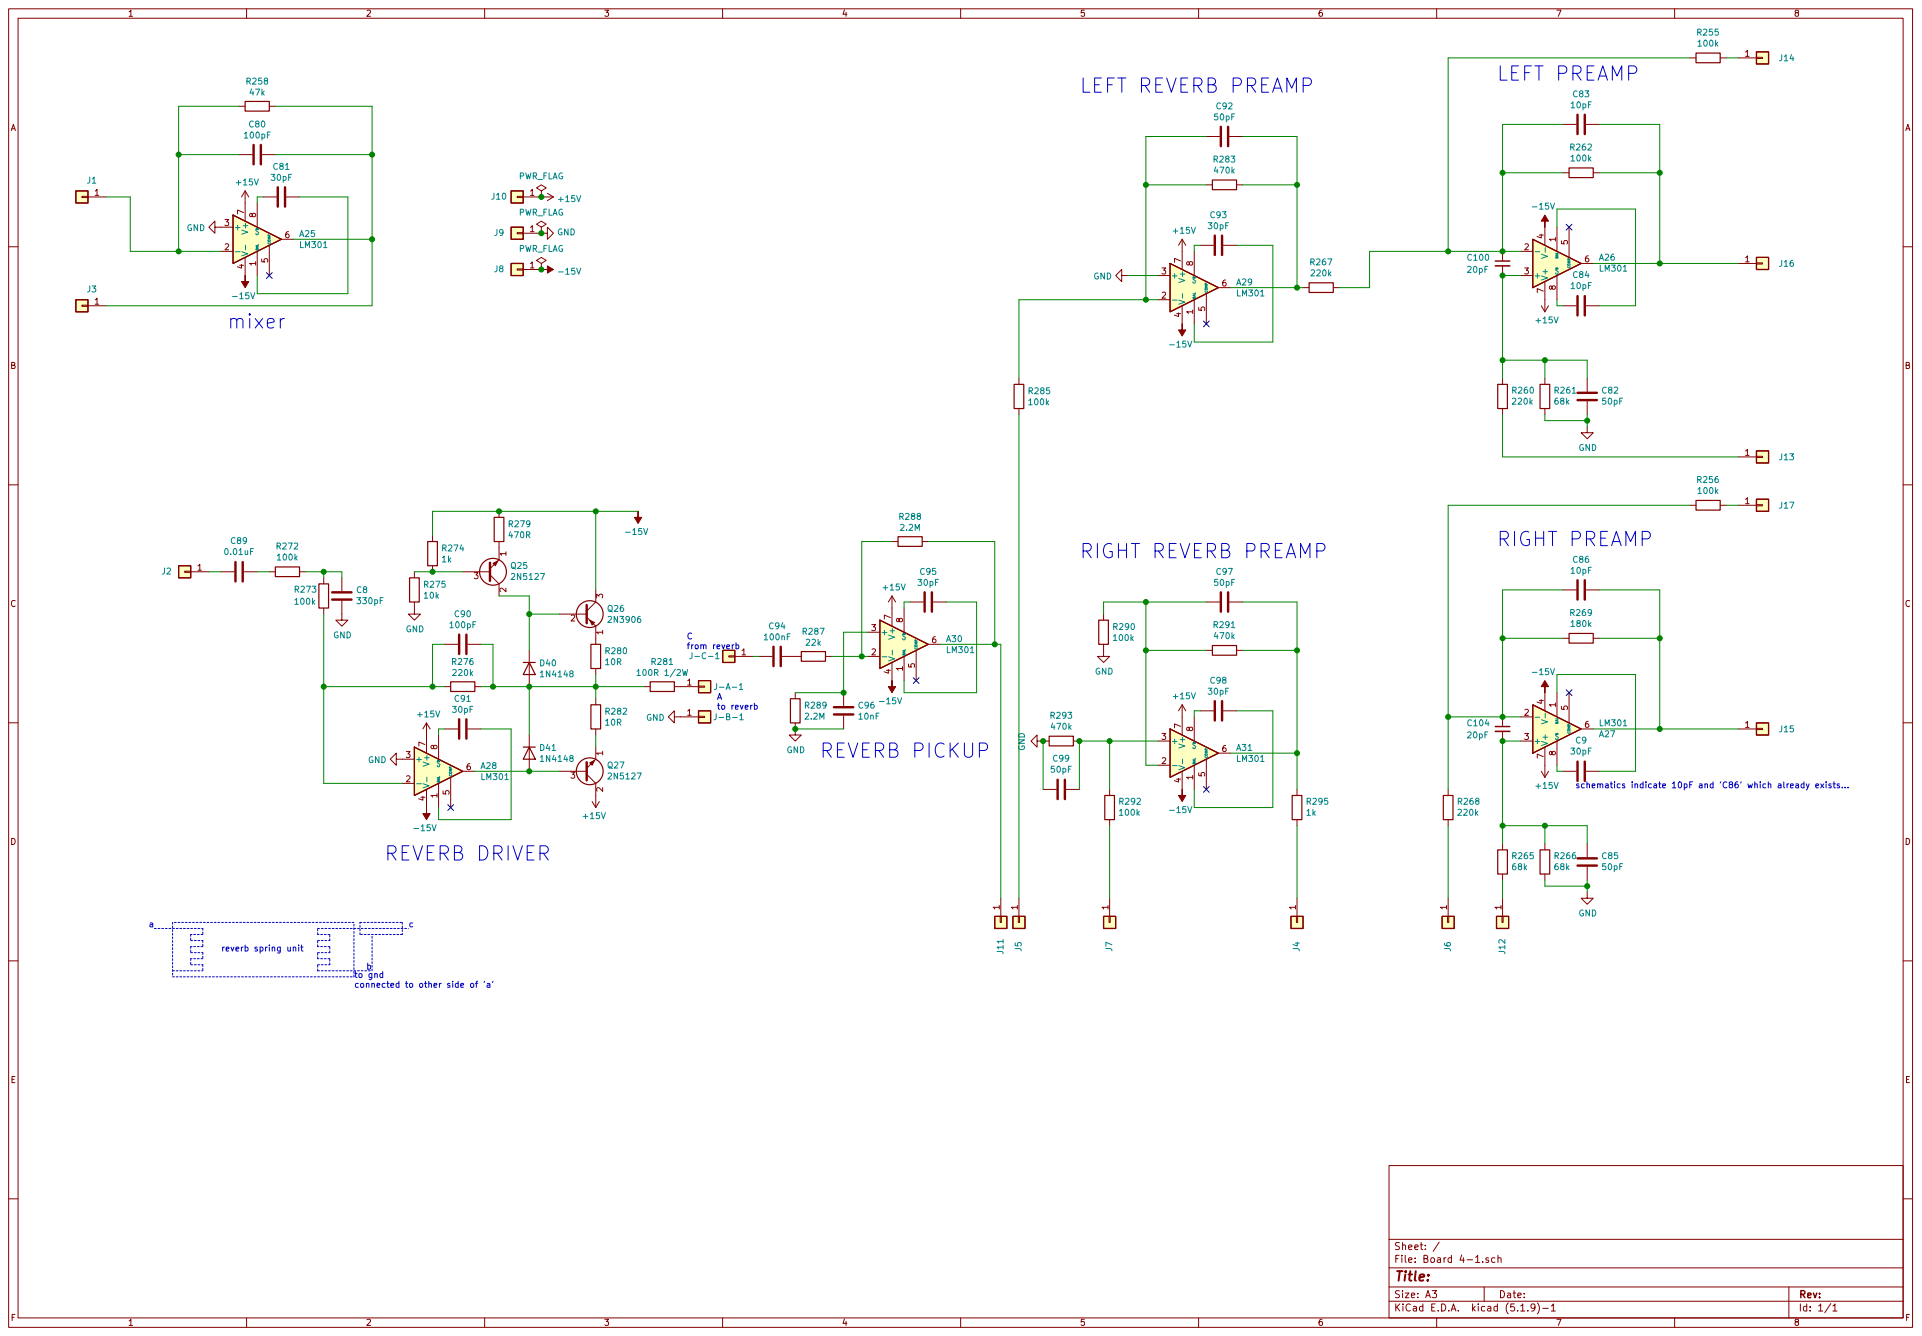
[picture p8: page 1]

schematics indicate 10pF and 'C86' which already exists...

Id: 1/1 Title: File: Board 4-1.sch Sheet: /

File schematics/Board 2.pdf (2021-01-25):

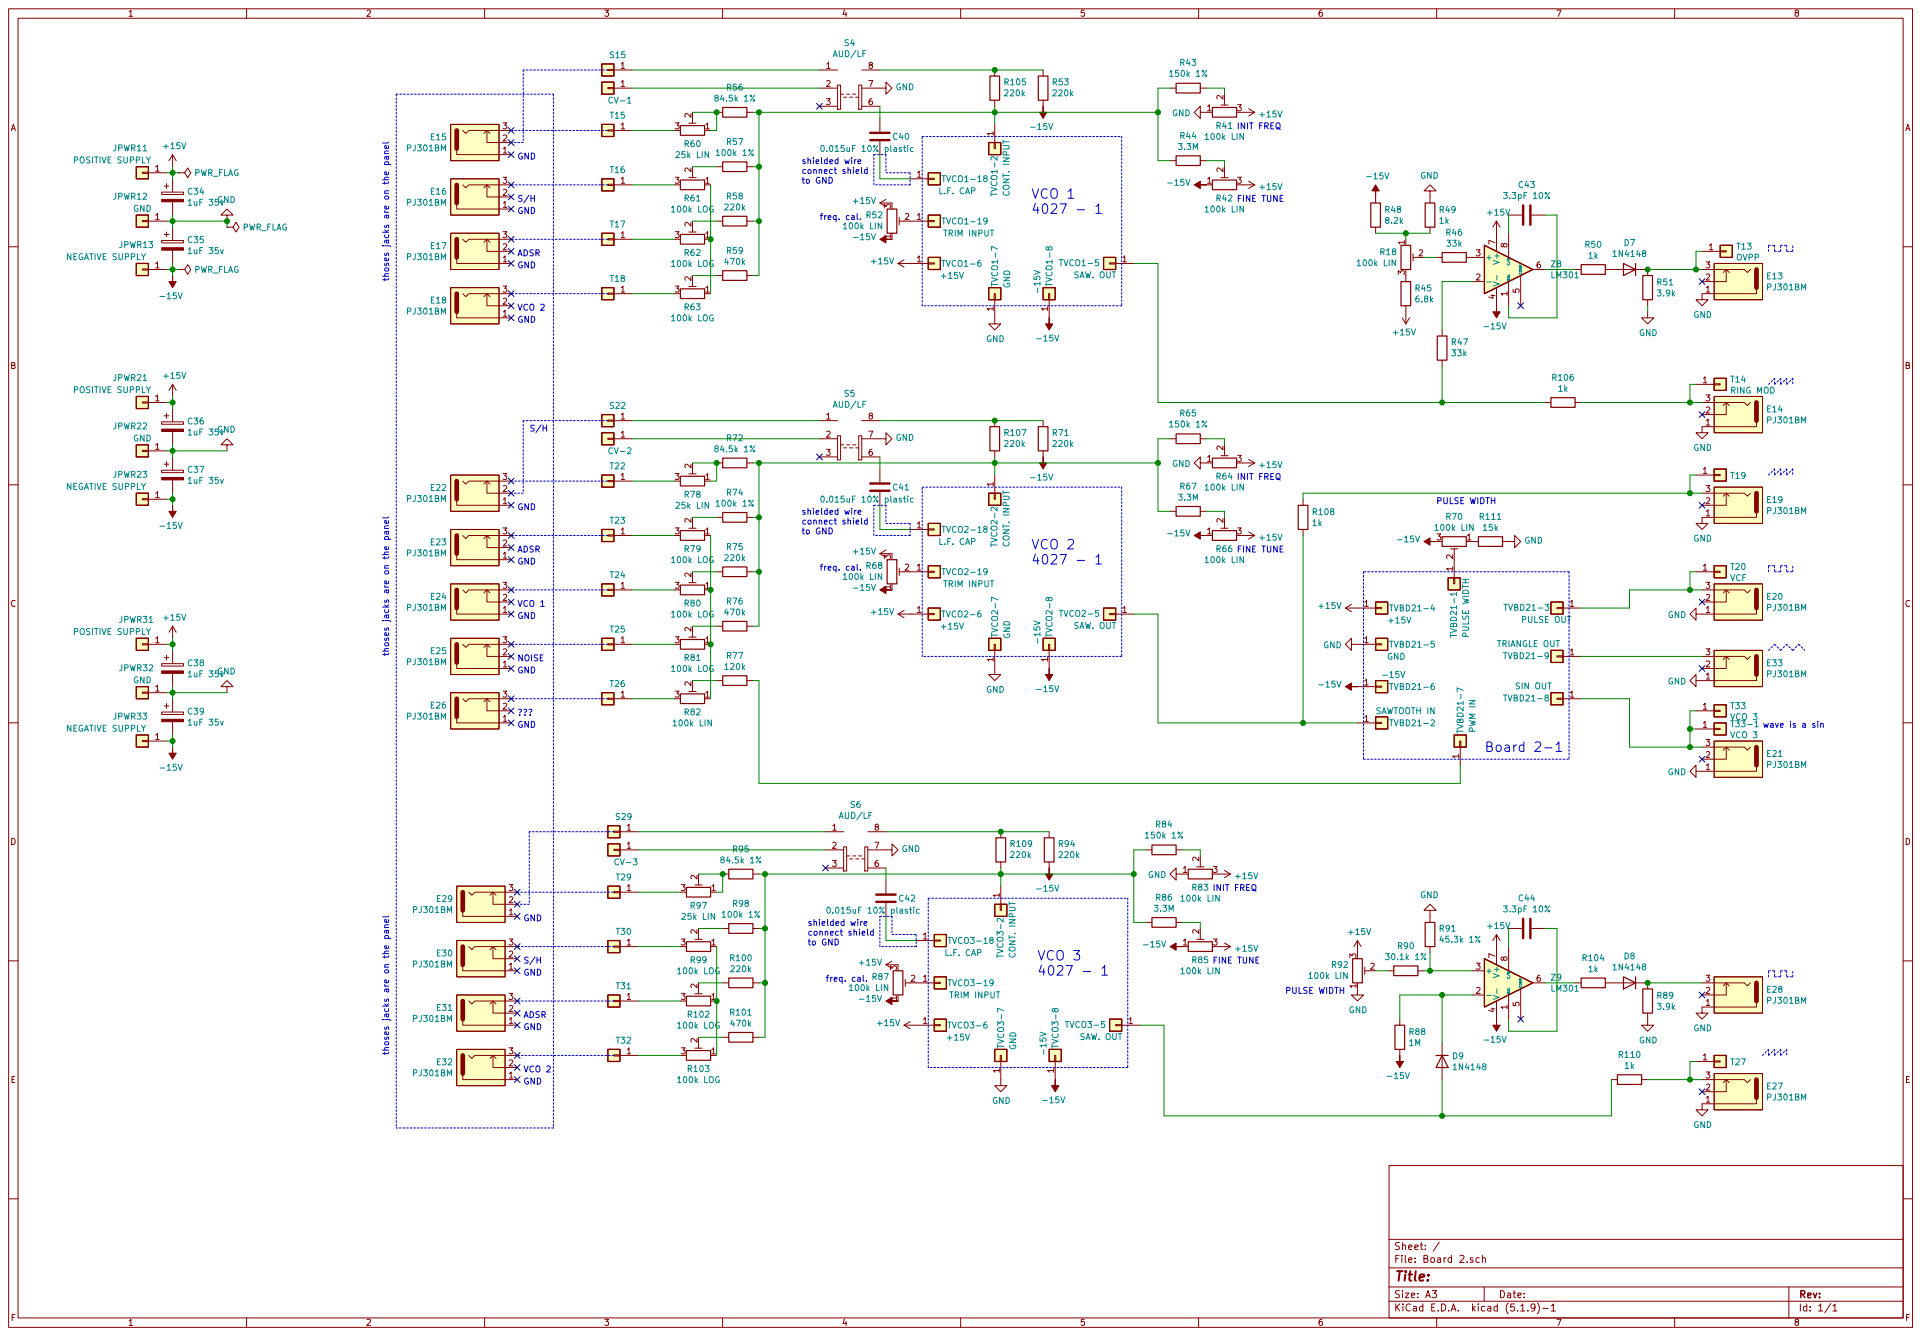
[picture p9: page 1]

freq. cal. shielded wire
connect shield
to GND

wave is a sin PULSE WIDTH

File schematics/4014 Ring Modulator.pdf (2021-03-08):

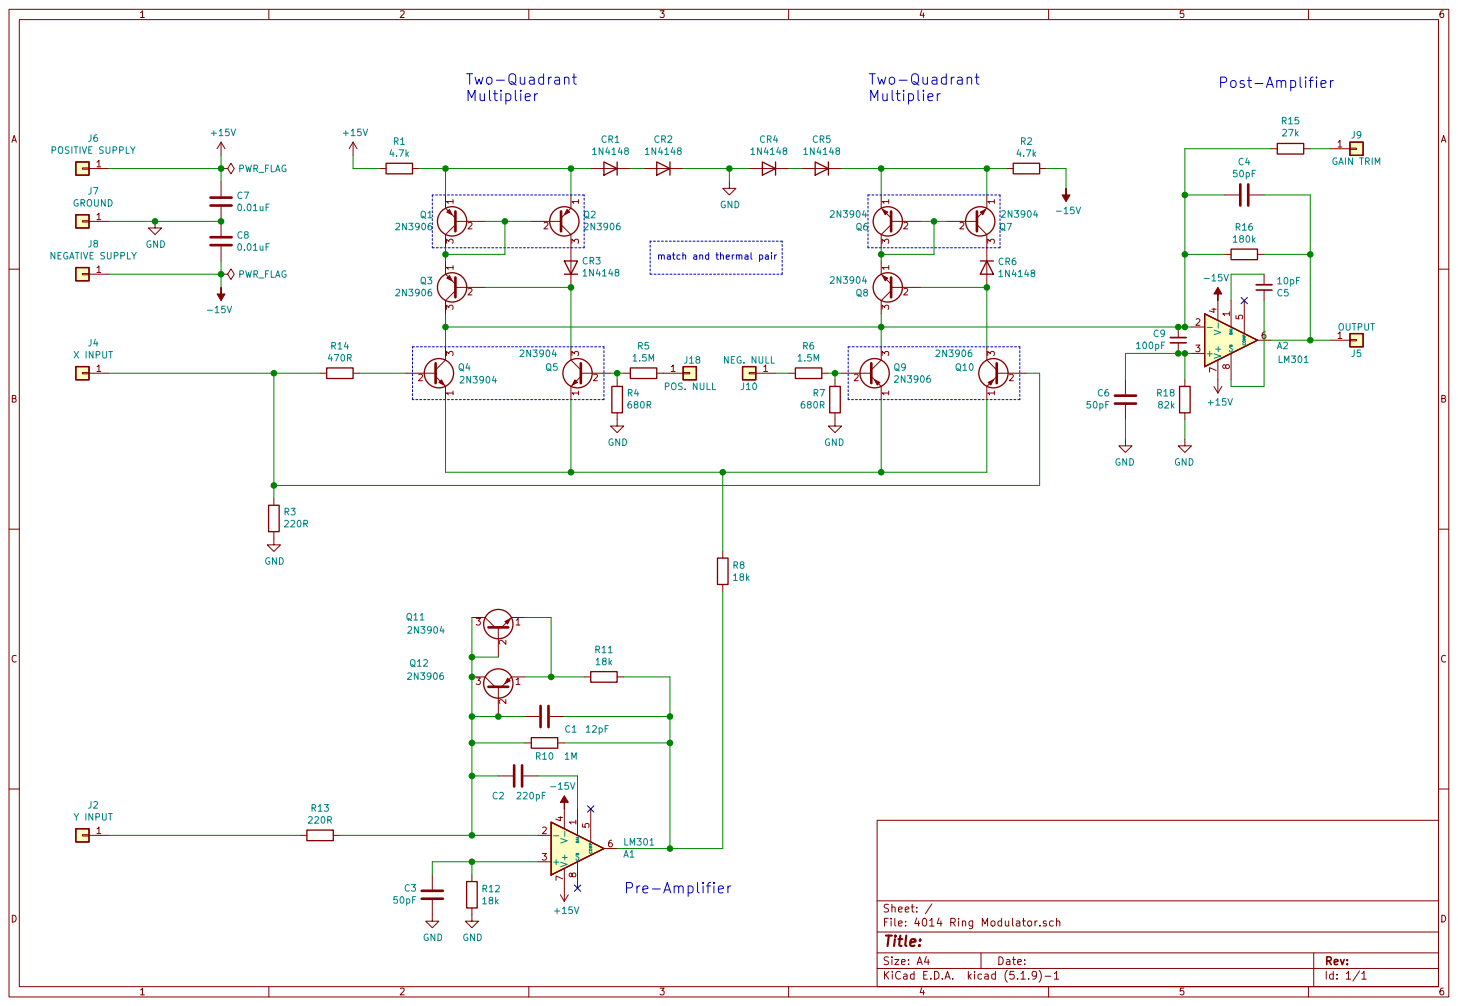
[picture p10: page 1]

match and thermal pair

File: 4014 Ring Modulator.sch Sheet: /
Id: 1/1 Title:

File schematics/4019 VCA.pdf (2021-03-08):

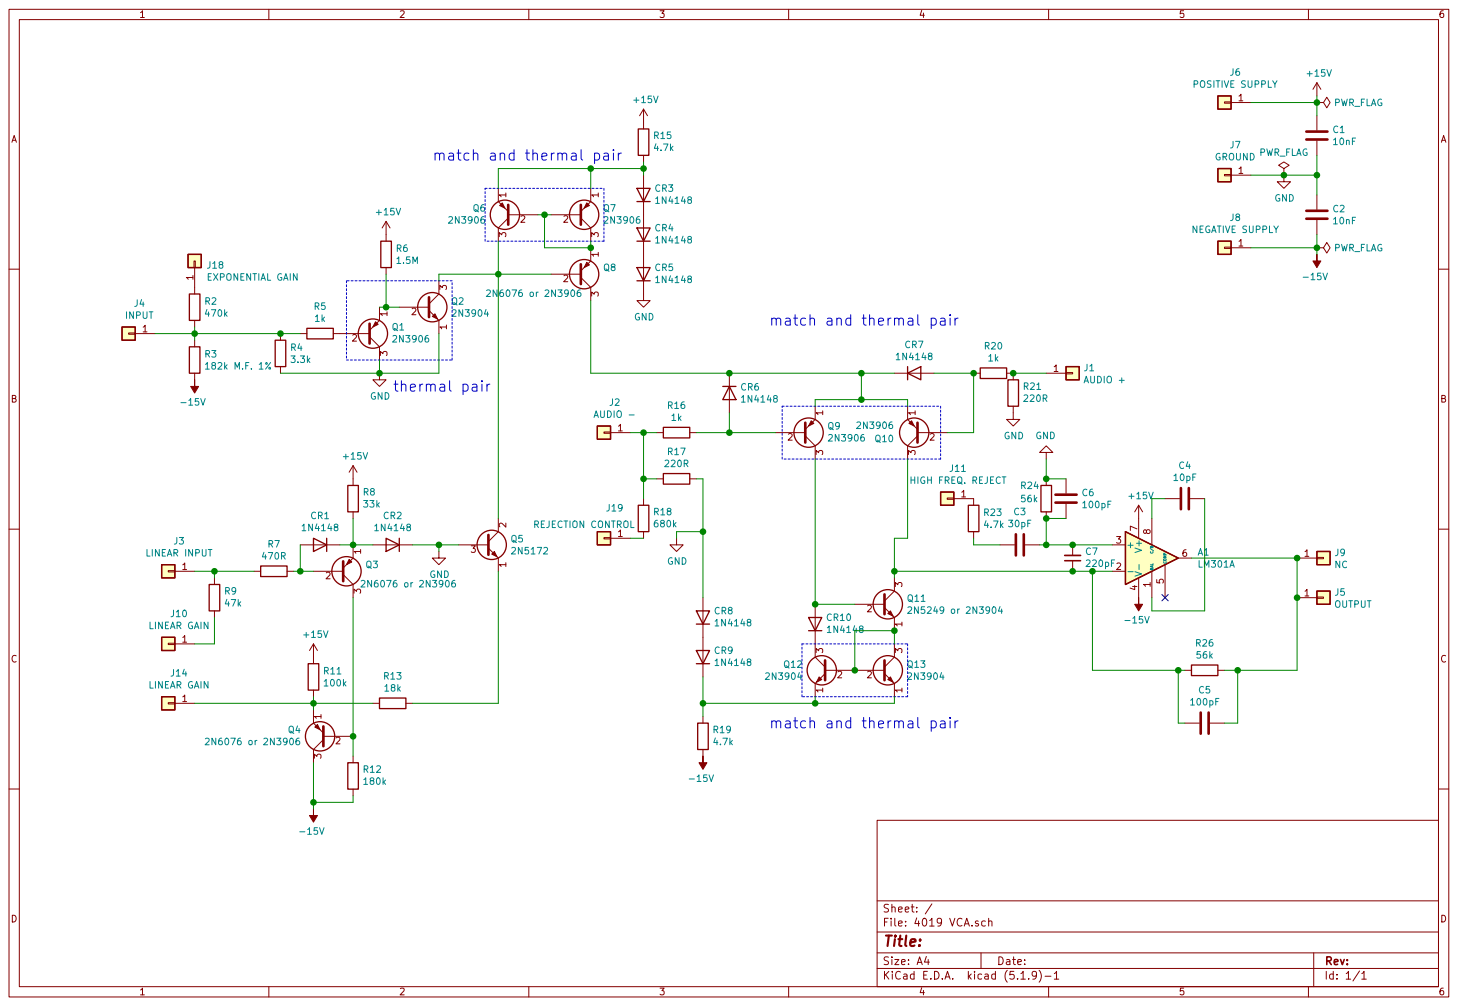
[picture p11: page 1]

match and thermal pair

Id: 1/1 Title: File: 4019 VCA.sch Sheet: /

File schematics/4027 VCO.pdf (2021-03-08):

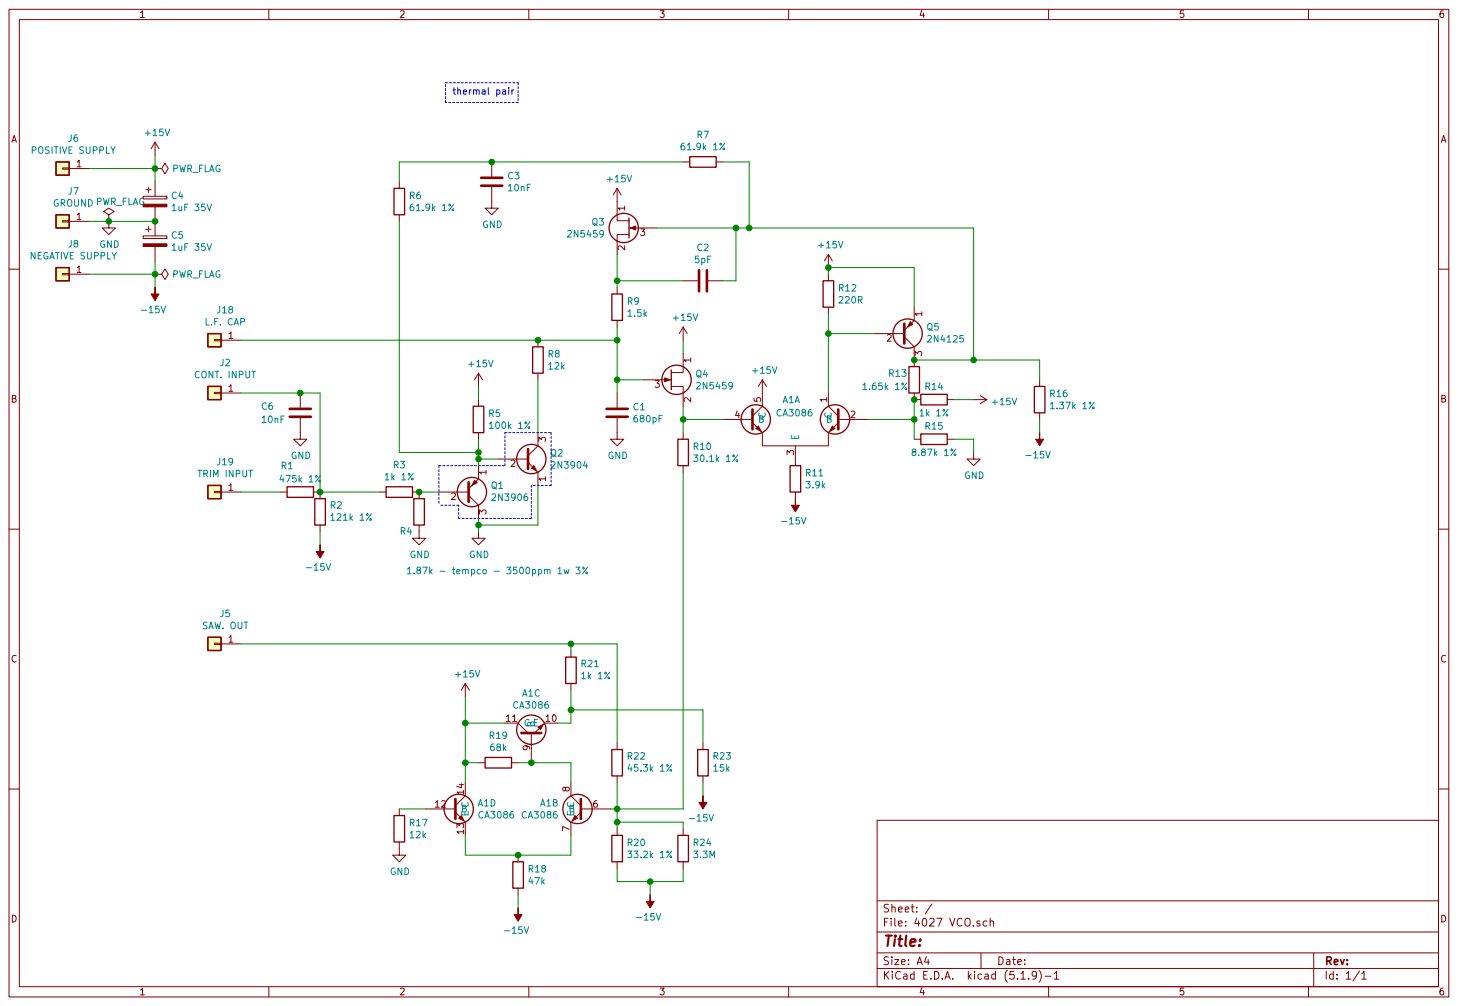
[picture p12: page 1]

Id: 1/1 Title: File: 4027 VCO.sch Sheet: /

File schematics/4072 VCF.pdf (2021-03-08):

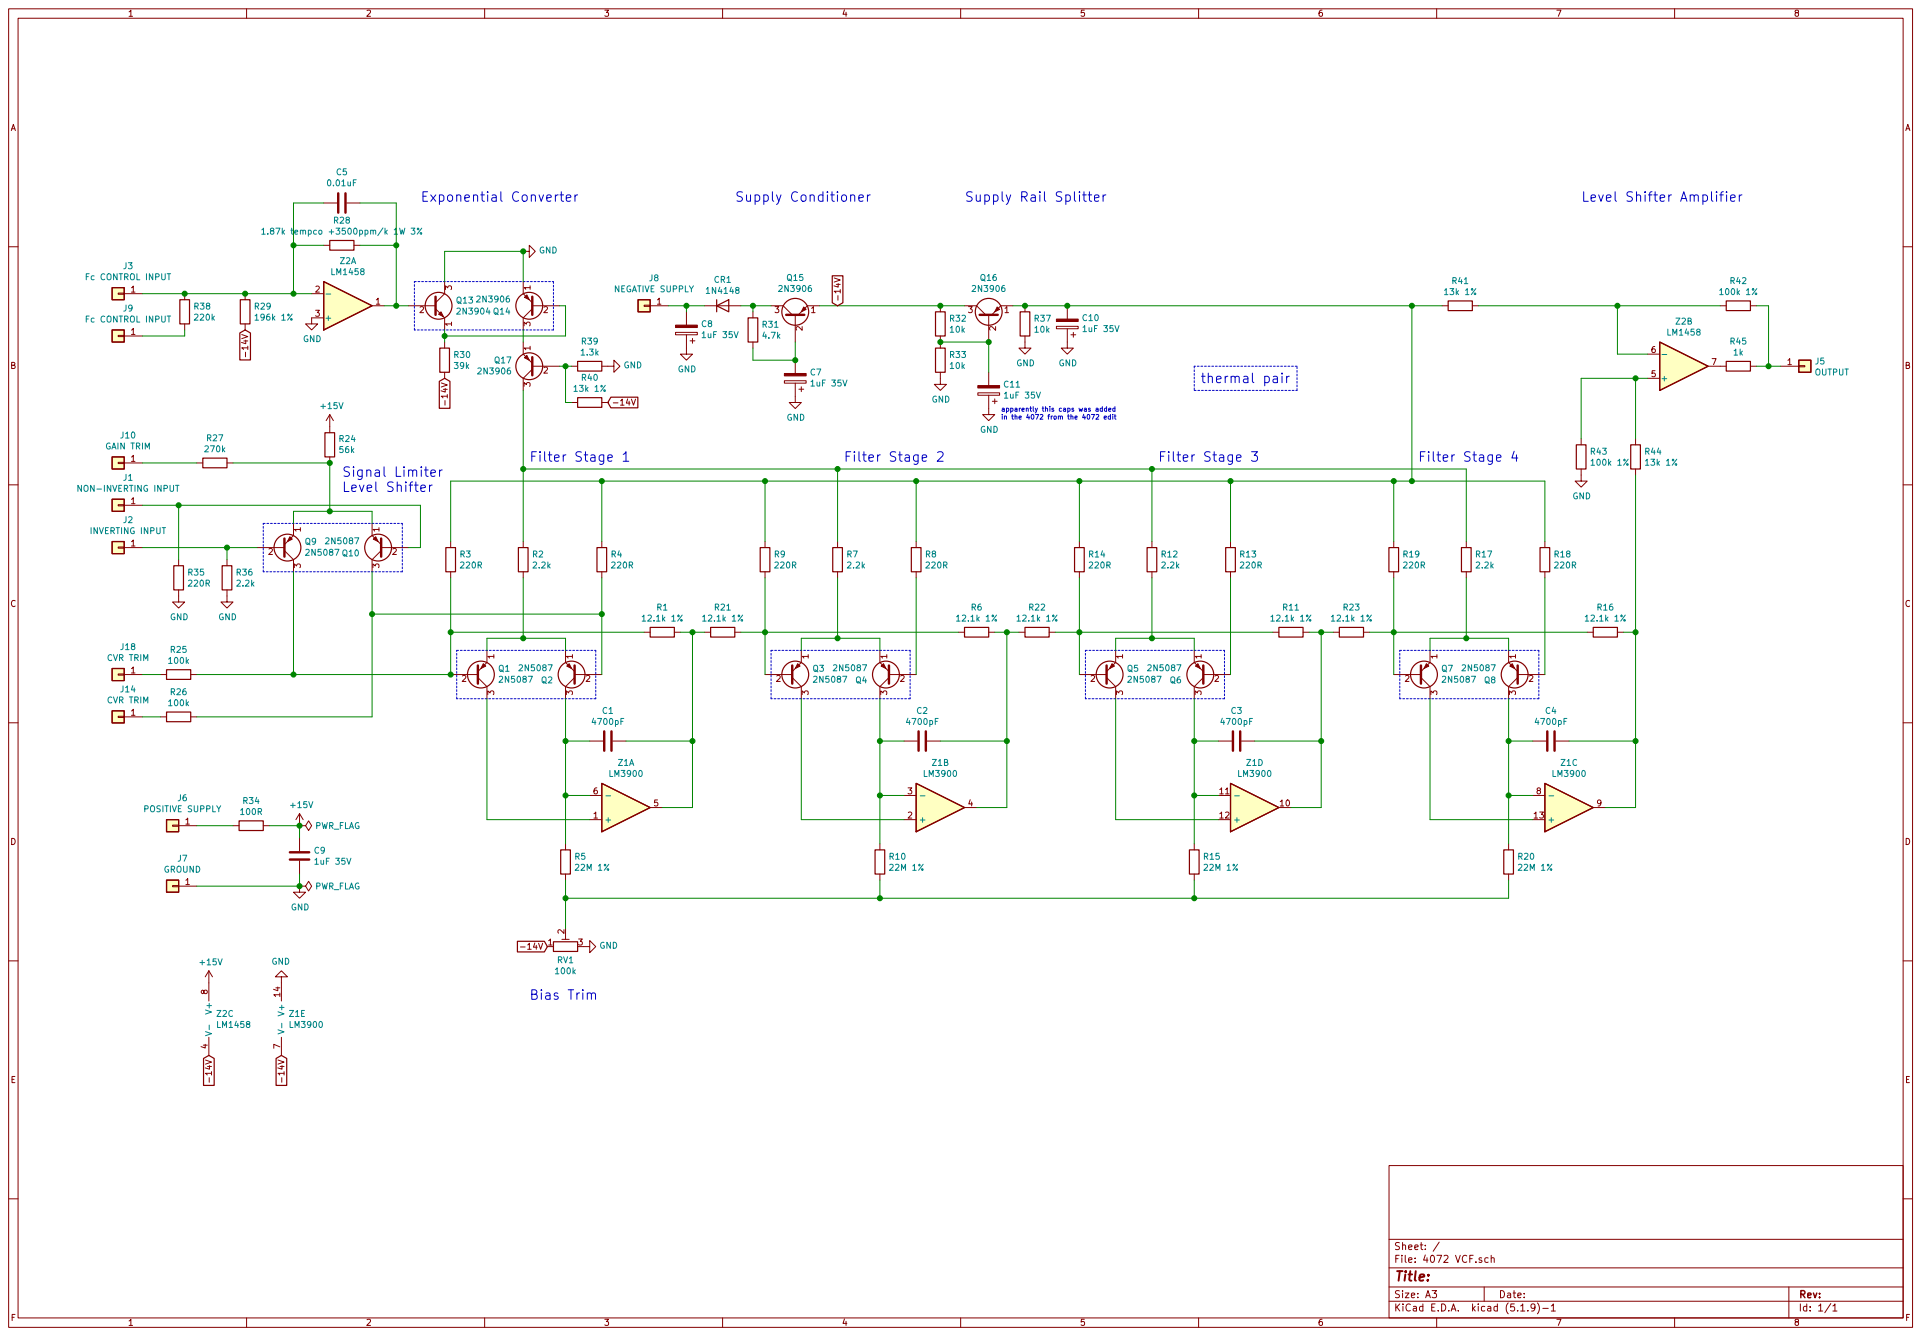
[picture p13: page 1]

apparently this caps was added
in the 4072 from the 4072 edit

Id: 1/1 Title: File: 4072 VCF.sch Sheet: /

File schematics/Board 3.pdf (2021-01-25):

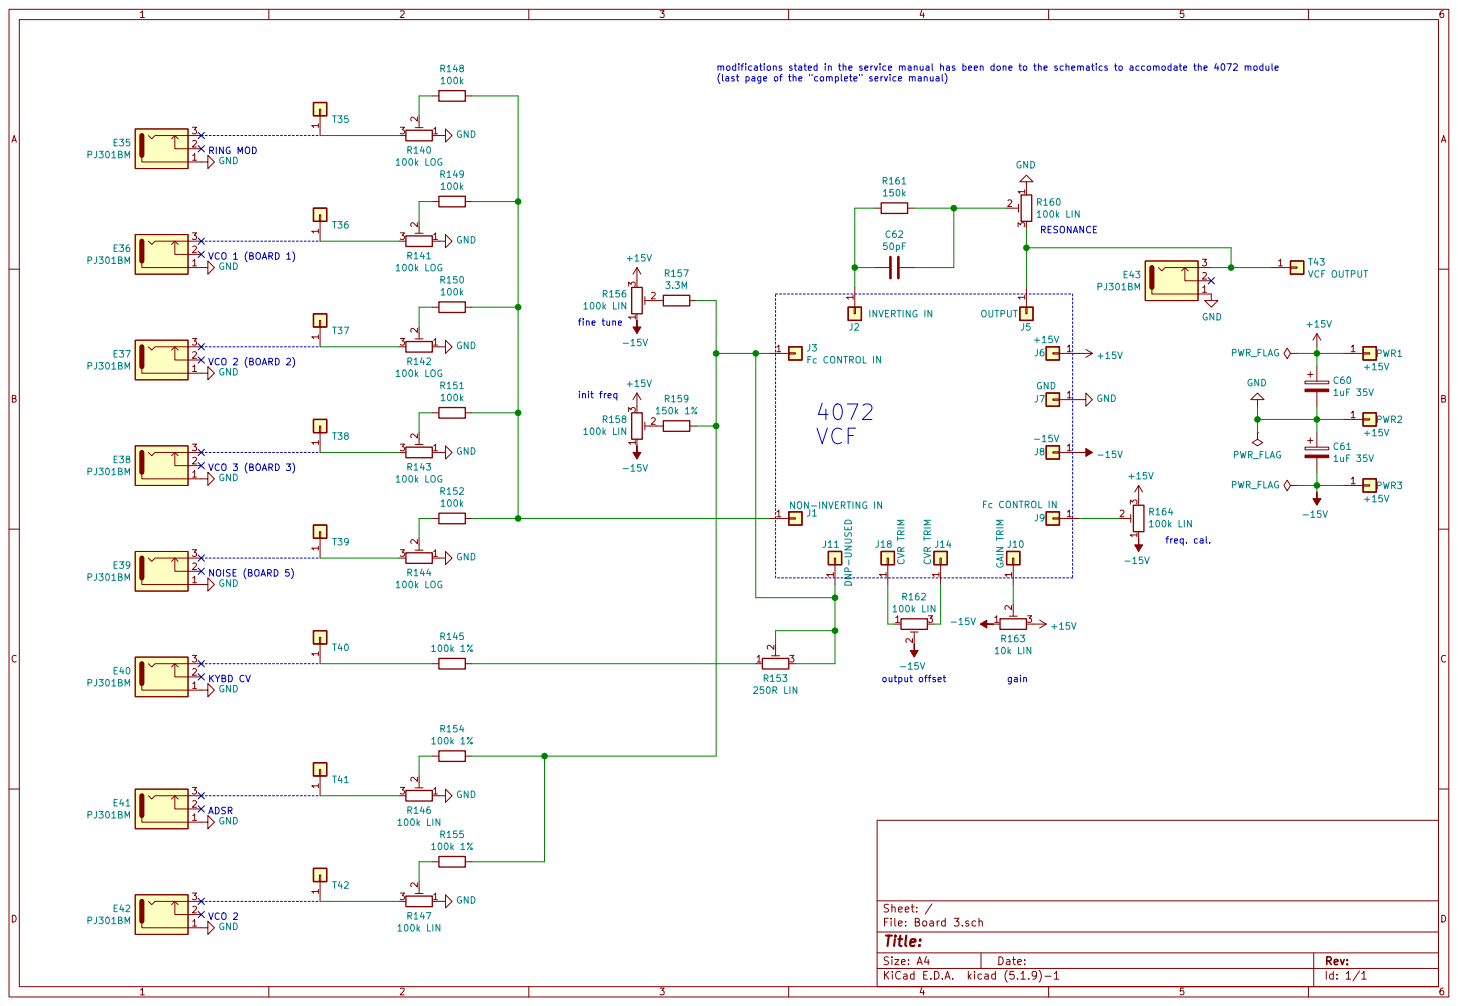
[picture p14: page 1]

(last page of the "complete" service manual) KYBD CV

freq. cal. RING MOD

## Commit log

2021-01-24 4014 schematics
    [4014 Ring Modulator.kicad_pcb, 4014 Ring Modulator.sch]
2021-01-24 4027 schematics
    [4027 VCO.kicad_pcb, 4027 VCO.sch]
2021-01-24 4072 schematics
    [4072 VCF.kicad_pcb, 4072 VCF.sch]
2021-01-24 4020 schematics
    [4020 ADSR.kicad_pcb, 4020 ADSR.sch]
2021-01-24 Fix some transistors pinouts
    [4020 ADSR.sch, 4027 VCO.sch]
2021-01-24 4022 schematics
    [4022 Noise.kicad_pcb, 4022 Noise.sch]
2021-01-24 4019 schematics
    [4019 VCA.kicad_pcb, 4019 VCA.sch]
2021-01-24 4015 schematics
    [4015 Sample and Hold.kicad_pcb, 4015 Sample and Hold.sch]
2021-01-24 various fixes
    [4019 VCA.sch, 4020 ADSR.sch, 4027 VCO.sch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]
2021-01-24 board 1 schematics
    [Board 1.kicad_pcb, Board 1.sch]
2021-01-24 fix J3 vs J4 typo
    [4014 Ring Modulator.sch, Board 1.sch]
2021-01-24 some fixes
    [Board 1.sch]
2021-01-25 add submodule; add jacks placeholders
    [Board 1.sch]
2021-01-25 fixes for the jack connectors
    [Board 1.sch]
2021-01-25 regen schematics pdf
2021-01-25 Board 2 schematics
    [Board 2.kicad_pcb, Board 2.sch]
2021-01-25 Board 2-1 schematics
    [Board 2-1.kicad_pcb, Board 2-1.sch]
2021-01-25 Board 3 schematics
    [Board 3.kicad_pcb, Board 3.sch]
2021-01-25 started board 4 schematics
    [Board 4.kicad_pcb, Board 4.sch]
2021-01-26 Board 4 finalized
    [Board 4.sch]
2021-01-26 Board 4-1 schematics
    [Board 4-1.kicad_pcb, Board 4-1.sch]
2021-01-26 Board 5 schematics
    [Board 5.kicad_pcb, Board 5.sch]
2021-01-27 Board 5-1 schematics
    [Board 5-1.kicad_pcb, Board 5-1.sch]
2021-01-27 Board 5 fix
    [Board 5.sch]
2021-01-27 board 5-1 fix values
    [Board 5-1.sch]
2021-01-28 Generate boms and netlists
    [4014 Ring Modulator.csv, 4015 Sample and Hold.csv, 4019 VCA.csv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]
2021-01-28 add missing bom
    [4072 VCF.csv]
2021-01-28 fix value
    [4022 Noise.csv, 4022 Noise.sch]
2021-01-28 Fix value in 4015
    [4015 Sample and Hold.csv, 4015 Sample and Hold.sch]
2021-01-28 Lots of fixes from patroche schematics/pcb
    [4027 VCO.csv, 4027 VCO.sch, Board 2-1.csv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]
2021-02-09 Add Front Panel cutout
    [ARP 2600 Panel.edited.dwg, ARP 2600 Panel.edited.dxf, ARP 2600 Panel.orig.dxf]
2021-02-09 remove the power switch as it's integrated in power socket and replace it with a second led
    [ARP 2600 Panel.edited.dwg, ARP 2600 Panel.edited.dxf]
